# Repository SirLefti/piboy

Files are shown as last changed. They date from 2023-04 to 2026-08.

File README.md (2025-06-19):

PiBoy
=========================



<br>




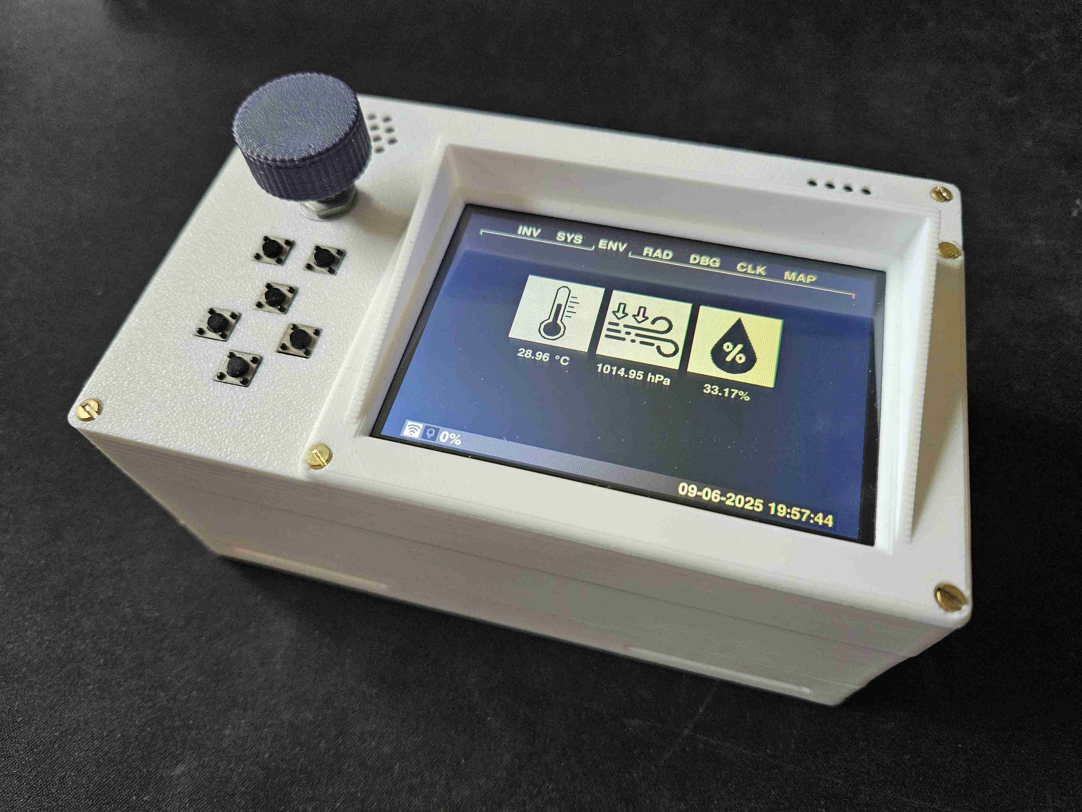
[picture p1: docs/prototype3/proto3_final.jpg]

Build your own Pip-Boy with some useful features for real-life using your Raspberry Pi.

## Features

#### File Manager App
Provides basic functions for moving, copying and deleting files and directories. Plug in a USB drive as a holo tape.

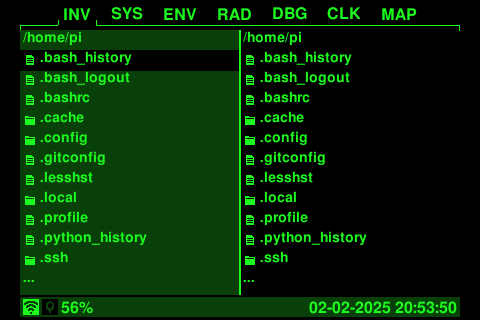
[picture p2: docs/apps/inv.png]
inv


#### System App
Can fetch and install updates from the git repository.

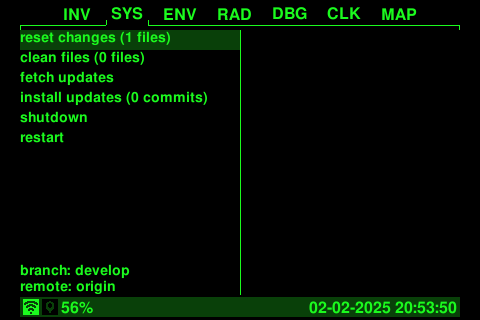
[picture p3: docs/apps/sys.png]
sys


#### Environment App
Provides useful information about your environment like temperature, atmospheric pressure and humidity.

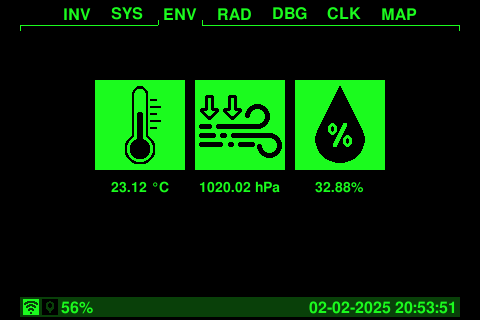
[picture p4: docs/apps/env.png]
env


#### Radio App
Actually more like a classic music player. Stay tuned!

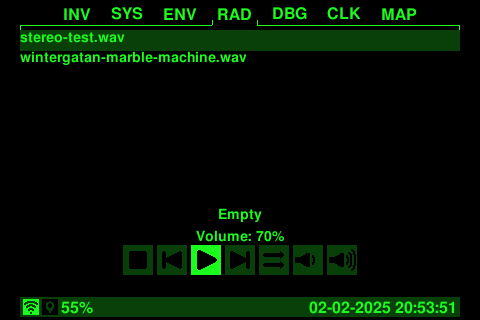
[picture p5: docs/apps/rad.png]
rad


#### Debug App
Shows the last pressed key to help you check the key wiring.

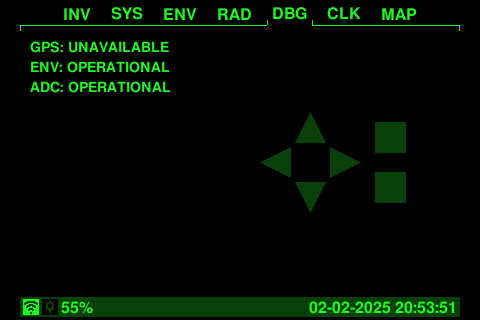
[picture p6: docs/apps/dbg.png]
dbg


#### Clock App
It just shows the time on a classic analog clock.

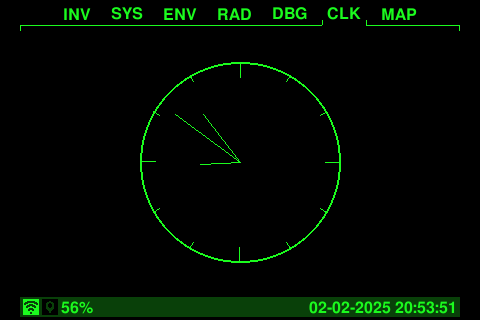
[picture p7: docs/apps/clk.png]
clk


#### Map App
Supports zooming and moving the map around. Don't get lost in the wasteland.

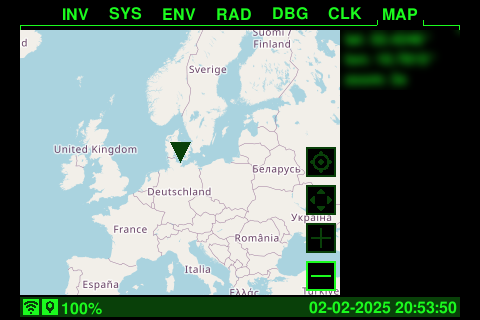
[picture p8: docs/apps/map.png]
map


## Hardware

Base:
- Raspberry Pi (full size board with all 40 pins recommended)
- Waveshare 3.5" SPI display (or [compatible](http://www.lcdwiki.com/3.5inch_RPi_Display))
- [GPIO edge extension](https://wiki.52pi.com/index.php?title=EP-0121)
- rotary encoder module (KY-040)
- 6x micro push buttons (6 mm x 6 mm)
- proto board (14x9 holes required)
- wires, general soldering stuff
- rotary encoder knob (optional, choose one you like)
- USB Wi-Fi adapter (optional, but recommended if your Pi does not have Wi-Fi onboard)

Modules:
- BME280 environment sensor
- NEO-6M GPS module
- DS3231 RTC clock (optional, but recommended, Raspberry Pi 5 features its own integrated RTC, that just requires to
connect a battery)
- ADS1115 analog-digital converter

Audio:
- PAM8403 amplifier with potentiometer
- 2x Mini Speakers (e.g. Loudity 16 mm or Adafruit Oval 20 mm x 30 mm)
- capacitor ~1000 µF, 10-25 V (optional, but recommended to stabilize power when turning on the PAM8403)
- potentiometer knob (optional, choose one you like)

Battery power:
- MT3608 power converter
- TP4056 battery charging controller
- 18650 battery cell (others can fit as well)
- toggle switch

Additional parts depending on case variant (see [Assembly](#assembly)). Check the following matrix to see which components and component groups are
supported by which case variant. Modules can be skipped entirely, but apps depending on them will not work properly.
Audio can be skipped as well if audio output is not needed. You can also use the audio jack of your Raspberry Pi if it
has one, but not all case provide an opening for it (but you can always make an opening for it). 

### Component Support Matrix

| Component | Prototype 1 | Prototype 2 | Prototype 3 |
|---|---|---|---|
| BME280 | &cross; | &check; | &check; |
| NEO-6M | &cross; | &check; | &check; |
| DS3231 | &cross; | &check; | &check; |
| ADS1115 | &cross; | *see note below* | &check; |
| Audio Components | &cross; | &cross; | &check; |
| Battery Components  | &cross; | &check; | &check; |
| GPIO Edge Extension | &cross; | *see note below* | &check; |

> **NOTE:**<br>
> ADS1115 can be squeezed into prototype 2 as well, but there is no dedicated place for it, and it is not documented.

> **NOTE:**<br>
> The GPIO edge extension can be used in one of the two variants of prototype 2.

### Raspberry Pi Model Support

PiBoy can work with models of the Raspberry Pi, that:

* have 40 GPIO pins (which excludes non-plus variants of the first generation)
* support the usual rectangular stand-off grid (which excludes again non-plus variants of the first generation)
* are ideally full width (which excludes all Zero models)
* are ideally full length (which excludes all A+ models and Zero models)

Zero models support only one half of the usual rectangular stand-off grid due to their size, which makes them less
stable in the case than full size models. Official support for Zero models is possible in future case variants. 

Short models like A+ and Zero models will also not reach the end of the case with their IO, Zero models do not even
provide IO on that end. This will prevent you from plugging in USB drives and it will look odd. Apart from that, they
can be used as well.

In short, all models with ethernet and 4x USB are ideal, *BUT* there is one exception: The model 4B swapped the 
positions of the ethernet and USB ports, which requires different structures in the case around the IO. The model 5 went
back to the old layout, and this will most likely be used in future models as well. Prototypes 1 and 2 are using the old
layout as well, making them incompatible with the 4B. Prototype 3 introduces replaceable IO plates to support both
layouts. You can also design your own IO plate to make it compatible with other single board computers, that have a
completely different IO layout.

## Installation

All guides are using Raspberry OS based on Debian Bookworm.

Install system dependencies:
````bash
sudo apt install git libopenjp2-7 libportaudio2 libopenblas0 python3-rpi-lgpio fonts-freefont-ttf
````

Call `sudo raspi-config`, select `Interface Options > SPI` and choose `Yes` to enable SPI.
Then select `Interface Options > I2C` and choose `Yes` to enable I2C.
Then also select `Interface Options > Serial Port` and choose `No` in the first pop-up and `Yes` in the second
pop-up. The last pop-up should then inform you, that the serial login shell is disabled and the serial interface is
enabled.

Clone repository and go into it:
````bash
git clone https://github.com/SirLefti/piboy
cd piboy
````

Create a virtual environment:
````bash
python -m venv .venv
````

Install python dependencies:
````bash
.venv/bin/pip install -r requirements-pi.txt
````

Now head over to the [module specific instructions](#module-specific-instructions) section and check the instructions of
each module you want to use. Some of them require additional steps to make them work. They all provide information to
validate that the module is configured and wired correctly.

Create a systemd service in ``/etc/systemd/system/piboy.service``:
````ini
[Unit]
Description=PiBoy Python Script
After=network.target

[Service]
Type=simple
WorkingDirectory=/home/pi/piboy
ExecStart=/home/pi/piboy/.venv/bin/python -u /home/pi/piboy/piboy.py
Restart=on-failure
User=pi
Group=pi

[Install]
WantedBy=multi-user.target
````

Reload to get the new configuration:
````bash
sudo systemctl daemon-reload
````

Activate the new service:
````bash
sudo systemctl enable piboy.service
````

Either restart the Pi or start the service manually:
````bash
sudo systemctl start piboy.service
````

## Configuration

On first run, the PiBoy script will create a ``config.yaml`` if not found. In that config file, you can configure
everything that relates to appearance and wiring. When running on a Raspberry Pi, ``dev_move`` must be set to ``false``
if not set by default. For development, it must be set to ``true`` instead, obviously. This setting automatically loads
the right input and display modules. On a Raspberry Pi, ``ILI9486Display`` and ``GPIOInput`` are being used. For
development, ``TkInteraction`` or ``SelfManagedTkInteraction`` can be used, both implement full input and display
functionality.

You can define additional color groups under ``app_config/modes`` for your own theme and set the index at
``app_config/color_mode``. The first default color group is the traditional classic green theme, the second is a yellow
power armor theme.

This project uses FreeSansBold as default font. If the font cannot be found despite being installed, or you do not want
to install it, place the ``FreeSansBold.ttf`` in the root directory as a workaround.

## Assembly

See [instructions for prototype 1](docs/prototype1/ASSEMBLY.md).

See [instructions for prototype 2](docs/prototype2/ASSEMBLY.md).

See [instructions for prototype 3](docs/prototype3/ASSEMBLY.md).

### Module specific instructions

* [BME280 environmental sensor](docs/BME280.md)
* [DS3231 RTC clock](docs/DS3231.md)
* [NEO-6M GPS module](docs/NEO-6M.md)
* [ADS1115 analog-digital converter](docs/ADS1115.md)
* [KY-040 rotary encoder](docs/rotary-encoder.md)
* [Keypad](docs/keypad.md)
* [Power circuit](docs/power-circuit.md)

## Post-Install

### Wi-Fi connection

You might want to add another Wi-Fi connection, e.g. to your phone, when you are out of your homes Wi-Fi range. Get in
the range of the Wi-Fi you want to add and check, if your device can see it:
````bash
nmcli dev wifi
````
If your Wi-Fi is not found immediately, wait a bit and run the command again.

If it was found, you can configure the connection (replace `<wifi-ssid>` and `<wifi-password>`):
````bash
sudo nmcli dev wifi connect <wifi-ssid> password <wifi-password>
````
When you were connected via `ssh`, the connection might reset due to the network change.

Network configurations are saved at `/etc/NetworkManager/system-connections`. Refer to the documentation of `nmcli` for
further details.

## Roadmap

We are feature complete. But there is still room for software and case improvements.

* [x] display driver
* [x] project base
* [x] build documentation / guide
* [x] case
* [x] file manager app
* [x] map app
* [x] radio app
* [x] environment sensors (temperature, humidity, ...)
* [x] GPS module
* [x] battery power
* [x] speaker for radio app
* [x] battery status
* [x] auto-mount usb drives
* [x] improved case

## Issues

### PyAudio

`pyaudio` might require system dependencies to be installed. On macOS, install the `portaudio` dependency with MacPorts:
```bash
sudo port install portaudio
```
Then install the package with pip and pass the directories where to find the dependencies:
```bash
CFLAGS="-I/opt/local/include -L/opt/local/lib" .venv/bin/pip install pyaudio
```

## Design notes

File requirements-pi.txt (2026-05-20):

-r requirements.txt
# The following requirements are only used by the hardware modules for Raspberry Pi.
spidev >= 3.5
rpi-lgpio >= 0.6.0
RPi.bme280 >= 0.2.4
evdev >= 1.7.1

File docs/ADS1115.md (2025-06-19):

ADS1115 analog-to-digital converter
===================================

The ADS1115 is a four-channel ADC with 16-bit resolution communicating via I2C. It can be used to bring analog input to
platforms, that do not provide analog input themselves.

## Wiring

The analog input voltage cannot be higher than the supply voltage. Because the use case is to measure the battery
voltage, the supply voltage for the module must be 5 V. To measure the battery cell voltage, an analog input must be
connected to it.

| ADS1115 Pin | Raspberry Pi/Power Converter Pin |
|---|---|
| GND | Pi GND |
| VDD | Pi VCC (5 V) |
| SDA | Pi SDA (GPIO 2) |
| SCL | Pi SCL (GPIO 3) |
| A0 | MT3608 VIn+ |

I2C is a bus system. Other devices can be connected to the same pins, but still work at the same time if they have
different addresses. ADS1115 are usually using address 0x48. Most boards also have an ADDR pin that allows to select
from different addresses by connecting that pin to GND, VDD, SDA or SCL.

## Configuration

Install ``i2c-tools`` if not already done:
```bash
sudo apt install i2c-tools
```

Check if the module is recognized correctly:
```bash
sudo i2cdetect -y 1
```
This command should return an entry in the matrix for 0x48 (or a different address if the module has a different one,
example):
```
     0  1  2  3  4  5  6  7  8  9  a  b  c  d  e  f
00:                         -- -- -- -- -- -- -- --
10: -- -- -- -- -- -- -- -- -- -- -- -- -- -- -- --
20: -- -- -- -- -- -- -- -- -- -- -- -- -- -- -- --
30: -- -- -- -- -- -- -- -- -- -- -- -- -- -- -- --
40: -- -- -- -- -- -- -- -- 48 -- -- -- -- -- -- --
50: -- -- -- -- -- -- -- -- -- -- -- -- -- -- -- --
60: -- -- -- -- -- -- -- -- -- -- -- -- -- -- -- --
70: -- -- -- -- -- -- -- --
```

Open a python console and test it out:
```pycon
>>> import smbus2
>>> bus = smbus2.SMBus(1)
>>> address = 0x48  # address of your sensor board, as shown in i2cdetect
>>> channel = 0  # channel number that is connected to a voltage source
>>> config = [0b11000001 | (channel << 4), 0b10000011]
>>> bus.write_i2c_block_data(address, 0x01, config)
>>> word_data = bus.read_word_data(address, 0x00)
>>> raw_data = ((word_data & 0xFF) << 8) | (word_data >> 8)  # byte swap
>>> (raw_data if raw_data < 0x8000 else raw_data - 0x10000) * 6.144 / 0x8000
3.8289375  # example output
```

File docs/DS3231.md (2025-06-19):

DS3231 hardware RTC module
==========================

The DS3231 is a hardware RTC module communicating via I2C. This module can be used to keep the current time when the Pi
is powered off. When booting, the Pi has to resync the system time by either the network or a hardware clock. If no 
network is available, the hardware clock acts as a fallback.

## Wiring

DS3231 modules have typically six pins in total. We need just four of them.

| DS3231 Pin | Raspberry Pi Pin |
|---|---|
| GND | GND |
| VCC | VCC (3.3 V) |
| SDA | SDA (GPIO 2) |
| SCL | SCL (GPIO 3) |
| SQW | not connected |
| 32K | not connected |

I2C is a bus system. Other devices can be connected to the same pins, but still work at the same time if they have
different addresses. DS3231 are usually using address 0x68.

## Configuration

Install ``i2c-tools`` if not already done:
```bash
sudo apt install i2c-tools
```

Check if the module is recognized correctly:
```bash
sudo i2cdetect -y 1
```
This command should return an entry in the matrix for 0x68 (or a different address if the module has a different one,
example):
```
     0  1  2  3  4  5  6  7  8  9  a  b  c  d  e  f
00:                         -- -- -- -- -- -- -- --
10: -- -- -- -- -- -- -- -- -- -- -- -- -- -- -- --
20: -- -- -- -- -- -- -- -- -- -- -- -- -- -- -- --
30: -- -- -- -- -- -- -- -- -- -- -- -- -- -- -- --
40: -- -- -- -- -- -- -- -- -- -- -- -- -- -- -- --
50: -- -- -- -- -- -- -- 57 -- -- -- -- -- -- -- --
60: -- -- -- -- -- -- -- -- 68 -- -- -- -- -- -- --
70: -- -- -- -- -- -- -- --
```
The entry on 0x57 is apparently the EEPROM found on the module.

Add the following entry to `/boot/firmware/config.txt`:
```
dtoverlay=i2c-rtc,ds3231
```

Reboot the pi and run the command again:
```bash
sudo i2cdetect -y 1
```

The address should now be marked as `UU`, which indicates that the devices is being used by a system driver (example):
```
     0  1  2  3  4  5  6  7  8  9  a  b  c  d  e  f
00:                         -- -- -- -- -- -- -- --
10: -- -- -- -- -- -- -- -- -- -- -- -- -- -- -- --
20: -- -- -- -- -- -- -- -- -- -- -- -- -- -- -- --
30: -- -- -- -- -- -- -- -- -- -- -- -- -- -- -- --
40: -- -- -- -- -- -- -- -- -- -- -- -- -- -- -- --
50: -- -- -- -- -- -- -- 57 -- -- -- -- -- -- -- --
60: -- -- -- -- -- -- -- -- UU -- -- -- -- -- -- --
70: -- -- -- -- -- -- -- --
```

Checking if it really works can be a bit tricky. The simplest way is having the display attached and the script
automatically running, because it shows date and time on the display. Make sure it is not connected to the network or
internet by removing the Wi-Fi adapter or ethernet cable if you are using one of those, or just by leaving your Wi-Fi
range when you are using onboard Wi-Fi.

Shut down the Pi and wait some time before booting it up again. If the time shown is relatively close to a reference
clock, the module was wired and configured correctly.

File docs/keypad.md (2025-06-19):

Keypad
======

The keypad uses six micro push buttons for a simple d-pad and two additional buttons.

## Parts
* 6x micro push buttons
* perf board/proto board (14x9 holes required)
* wires, general soldering stuff

## Assembly

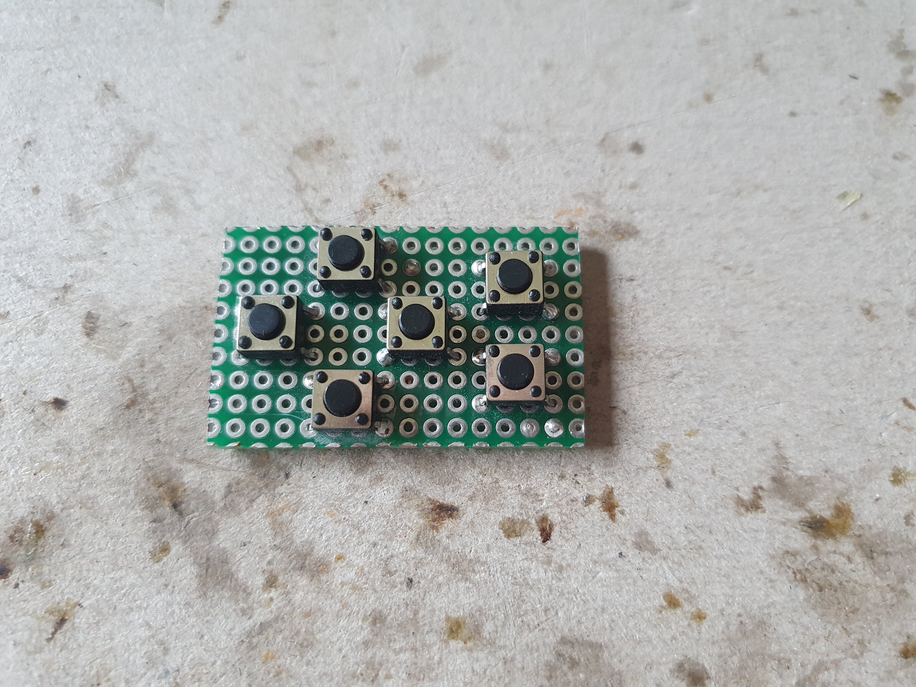
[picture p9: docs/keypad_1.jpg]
keypad_1

Mount and solder the micro push buttons as shown.

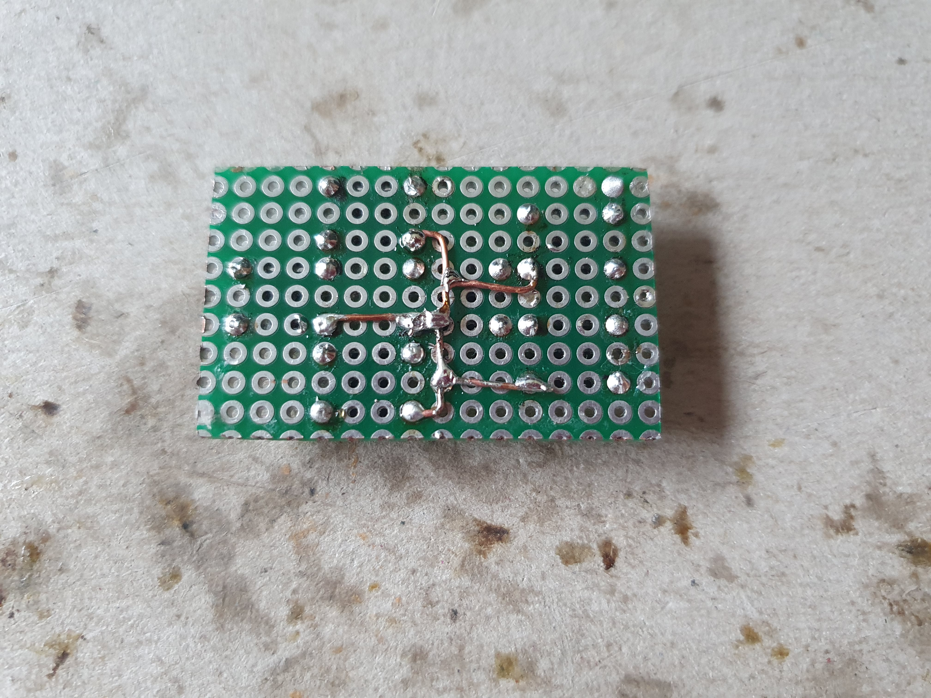
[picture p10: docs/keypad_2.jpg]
keypad_2

Solder a common ground wire.

Cut the edges of the board if it is too big to fit.

**NOTE:** As you can see, a single button needs 3x4 holes and has four legs, with two legs being connected to each other
internally. To connect each button to the Pi, use the leg of the button, that is just **one** hole apart from that one,
that is connected to the common ground wire. It might feel more intuitive to you to use the one, that is **two** holes
apart from the common ground wire, and I did this mistake several times as well. It is the other one. It does not damage
the Pi when it is soldered the wrong way, it is just not working.

## Wiring

| Keypad Pin | Raspberry Pi Pin |
|---|---|
| GND | GND |
| button UP | GPIO 5 |
| button DOWN  | GPIO 6 |
| button LEFT  | GPIO 12 |
| button RIGHT | GPIO 13 |
| button A | GPIO 16 |
| button B | GPIO 26 |

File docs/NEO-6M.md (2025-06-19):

NEO-6M GPS module
================

The NEO-6M is a GPS module communicating via UART. It provides the current position of the device.

## Wiring

The NEO-6M module has four pins in total.

| NEO-6M Pin | Raspberry Pi Pin |
|---|---|
| GND | GND |
| VCC | VCC (5 V) |
| RX | TX (GPIO 14) |
| TX | RX (GPIO 15) |

The RX pin on the module can be skipped and is not needed for now.

## Configuration

Check if the module is wired correctly and sends some data:
```bash
cat /dev/serial0
```
It might return lines like this:
```
$GPTXT,01,01,01,NMEA unknown msg*58
```

If not, try this instead:
```bash
tail -f /dev/serial0
```

If `/dev/serial0` does not exist, try it again with `/dev/ttyAMA0` instead. In that case, you have to change this value
in the `config.yaml` as well.

If the blue LED on the module is blinking, it has already found its position and sends messages with the position. Go
outside or close to a window and wait a few minutes if it does not blink.

Open a python console and test it out:
```pycon
>>> import serial
>>> import io
>>> import pynmea2
>>> device = serial.Serial('/dev/serial0', baudrate=9600, timeout=0.5)
>>> io_wrapper = io.TextIOWrapper(io.BufferedReader(device))
>>> while True:
...     data = io_wrapper.readline()
...     if data[0:6] == '$GPGLL':
...         message = pynmea2.parse(data)
...         print('lat:', message.latitude, 'lon:', message.longitude)
```

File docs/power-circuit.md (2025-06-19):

Power Circuit
=============

The power circuit provides battery power to this project, to use it without external power supply. It supports a 
standard 18650 battery cell, but can fit any other smaller sizes as well. 

## Parts
* 1x MT3608 power converter
* 1x TP4056 battery charging controller
* 1x 18650 Li-ion battery cell (others can fit as well)
* 1x toggle switch
* 1x capacitor ~1000 µF, 10-25 V (optional, but recommended, especially when using the PAM8403)
* wires and soldering stuff

## Assembly

Solder the parts together as shown in the table and image below.

**IMPORTANT:** Set up the power converter to output 5.0 V before soldering the Pi to it. The Pi has no fuses to protect
itself from over-voltage via the pins. Charge the battery before configuring it.

**NOTE**: The switch is placed between the battery/charging controller and the power converter, because the power
converter would drain the battery over time if it was permanently connected to it.

| from | to |
|---|---|
| battery+ | TP4056 B+ |
| battery- | TP4056 B- |
| TP4056 Out+ | Switch Center 1 |
| TP4056 Out- | Switch Center 2 |
| Switch Left 1 | MT3608 VIn+ |
| Switch Left 2 | MT3608 VIn- |
| MT3608 VOut+ | Pi Pin 2 (5V) |
| MT3608 VOut- | Pi Pin 6 (GND)  |
| Capacitor + (long leg)  | MT3608 VOut+ |
| Capacitor - (short leg) | MT3608 VOut- |

The complete circuit should look like this. Try to power it on like that to see if everything works. Also attach the
display module, because it has a relatively high power draw compared to the other components.
power-circuit
*Note: This example uses two separate cells instead of the single 18650 one. If using two separate cells, make sure they
are of the same type and have the same rated capacity. These are harvested from disposable e-vapes.*

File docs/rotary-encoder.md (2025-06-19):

Rotary Encoder
==============

A rotary encoder can be used in two different ways: By polling and by device overlay. Polling means checking the pins
over and over again in a short period of time, the device overlay on the other hand is an event based system. The device
overlay way is used here, because it is much more reliable.

## Wiring

A rotary encoder has two channels, channels A and B. On the KY-040 they are named CLK and DT for some reason, indicating
some clock and data pins, which is not really the case.

Connecting the rotary switch is optional. It can be used to call any function for debugging, like resetting the display.

| Rotary Encoder Pin | Raspberry Pi Pin |
|---|---|
| GND | GND |
| + | VCC (3.3 V) |
| CLK | GPIO 23 |
| DT | GPIO 22 |
| SW | GPIO 27 / NC |

## Configuration

To register the rotary encoder as a device, add this to `/boot/firmware/config.txt`:

```
dtoverlay=rotary-encoder,pin_a=22,pin_b=23,relative_axis=1,steps-per-period=1
```

Reboot the Pi.

Install ``evtest`` if not already done:
```bash
sudo apt install evtest
```

Calling ``evtest`` should return a list of input devices:
```
No device specified, trying to scan all of /dev/input/event*
Not running as root, no devices may be available.
Available devices:
/dev/input/event0:      rotary@16
/dev/input/event1:      vc4-hdmi
/dev/input/event2:      vc4-hdmi HDMI Jack
```

The rotary shows up as ``/dev/input/event0``. Quit the command with ``Ctrl+C``.

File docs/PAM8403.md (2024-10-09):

PAM8403 amplifier module
========================

The PAM8403 is a compact amplifier module to drive small speakers.

It comes in various variants, some include a potentiometer to control the volume. This is the recommended variant for
this project.

## Wiring and Configuration

The module usually uses 5 V. Two speakers can be connected.

| PAM8403 Pin | Raspberry Pi/Speaker Pin |
|---|---|
| Power - | Pi GND |
| Power + | Pi VCC (5 V) |
| Lout - | Left Speaker GND |
| Lout + | Left Speaker Signal |
| Rout - | Right Speaker GND |
| Rout + | Right Speaker Signal |
| L | *see below* |
| G | *see below* |
| R | *see below* |

The input can be connected in two ways:

---

### A: via 3.5 mm audio jack

Most boards (first to fourth generation inclusively) provide an audio jack for headphones. We can use this to connect
the signal to the amplifier. You can check out the
[Raspberry Pi Documentation](https://github.com/raspberrypi/documentation/blob/develop/documentation/asciidoc/computers/raspberry-pi/raspberry-pi-schematics.adoc)
for schematics. Most boards provide names checkpoints for audio that can be used to solder a connection to.

For Raspberry Pi 2 and 3 boards (probably also Pi 1, but it is not referenced in the schematics):

| PAM8403 Pin | Raspberry Pi Checkpoint |
|---|---|
| L | PP25 |
| G | PP6 |
| R | PP26 |

For Raspberry Pi 4 boards:

| PAM8403 Pin | Raspberry Pi Checkpoint |
|---|---|
| L | TP22 |
| G | TP7/TP8/TP9/TP12 |
| R | TP23 |

Raspberry Pi 5 (and probably onwards) and Zero Boards do not provide an audio jack. They can use the next variant.

---

### B: via GPIO pins

GPIO pins can be configured to output audio signals. To enable this, add this to `/boot/firmware/config.txt`:

```
dtoverlay=pwm-2chan,pin=18,func=2,pin2=19,func2=2
```

The input can then be wired as follows:

| PAM8403 Pin | Raspberry Pi Pin |
|---|---|
| L | GPIO 18 |
| G | GND |
| R | GPIO 19 |

---

To test it out, get some audio files and try to play them from the command line. You can use `aplay`, which is
preinstalled, to play `.wav` files. For `.mp3` files, you can use `mpg123`, which has to be installed separately.

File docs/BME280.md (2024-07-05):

BME280 environmental sensor
===========================

The BME280 is an environmental sensor communicating via I2C. The sensor can read the current temperature, humidity and
atmospheric pressure.

## Wiring

The BME280 has usually four pins and a single mounting hole. There might be other variants out there, but be careful:
Some shop might try fool you and sell you the cheaper BMP280 instead, which lacks the humidity feature and has usually
a different board with six pins and two mounting holes. The case parts are not prepared to mount this variant.

Also, following the datasheets, some variants needs to be supplied with 3.3 V, while others expect 5 V instead. Read
carefully.

In my case, it was documented with 3.3 V.

| BME280 Pin | Raspberry Pi Pin |
|---|---|
| GND | GND |
| VIn | VCC (3.3 V) |
| SDA | SDA (GPIO 2) |
| SCL | SCL (GPIO 3) |

I2C is a bus system. Other devices can be connected to the same pins, but still work at the same time if they have
different addresses. BME280 are usually using address 0x76.

## Configuration

Install ``i2c-tools`` if not already done:
```bash
sudo apt install i2c-tools
```

Check if the module is recognized correctly:
```bash
sudo i2cdetect -y 1
```
This command should return an entry in the matrix for 0x76 (or a different address if the module has a different one,
example):
```
     0  1  2  3  4  5  6  7  8  9  a  b  c  d  e  f
00:                         -- -- -- -- -- -- -- --
10: -- -- -- -- -- -- -- -- -- -- -- -- -- -- -- --
20: -- -- -- -- -- -- -- -- -- -- -- -- -- -- -- --
30: -- -- -- -- -- -- -- -- -- -- -- -- -- -- -- --
40: -- -- -- -- -- -- -- -- -- -- -- -- -- -- -- --
50: -- -- -- -- -- -- -- -- -- -- -- -- -- -- -- --
60: -- -- -- -- -- -- -- -- -- -- -- -- -- -- -- --
70: -- -- -- -- -- -- 76 --
```

Open a python console and test it out:
```pycon
>>> import smbus2
>>> import bme280
>>> bus = smbus2.SMBus(1)
>>> address = 0x76  # address of your sensor board, as shown in i2cdetect
>>> bme280.sample(bus, address)
compensated_reading(id=... timestamp=..., temp=23.020 °C, pressure=1002.68 hPa, humidity=38.15 % rH)
```
If the reading returns just zeroes for `temp`, `pressure` and `humidity`, check your wiring. The reading was not
successful, unless you are living in an extremely dry, but cool place in outer space, and the values are actually
correct.

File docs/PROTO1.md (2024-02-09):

Case Prototype 1
================

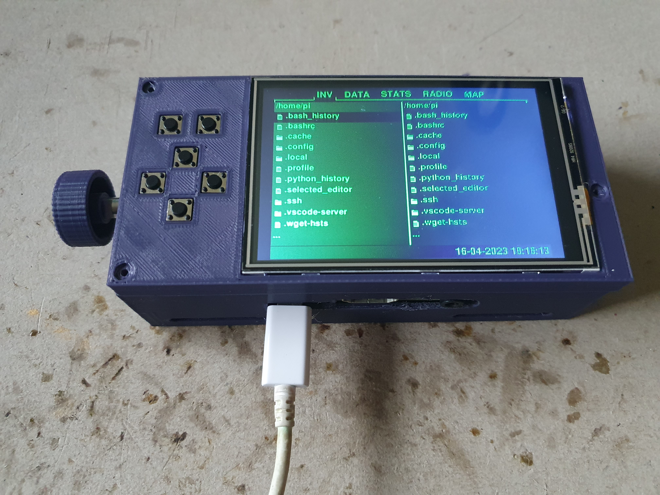
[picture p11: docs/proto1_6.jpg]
proto1_final


## Parts
* [base part](parts/proto1/Proto1.1-base.stl)
* [top part](parts/proto1/Proto1.1-top.stl)
* 3x M2x25
* 6x micro push buttons (6mm x 6mm)
* rotary encoder (KY-040 module)
* perf board/proto board (14x9 holes required)
* wires, general soldering stuff
* rotary encoder knob (optional)

**Made for Raspberry Pi 2 Model B**

## Goal

* minimalistic case as a proof of concept
* test button position and alignment
* test bulge for forearm
* test space for a potential strap
* test printing and removing support structures
* no extra space for extra hardware modules or battery

## Evaluation

* forearm bulging requires huge support structure, maybe just make it flat or introduce a separate part and print it
upside down
* support posts for the pi board also require support structures beneath, because a strap should go underneath
* screw holes are pretty tight, but might allow to omit nuts
* hole for rotary encoder is a bit tight
* might need a custom knob which is flush with the case
* knob might be too close to your forearm, depending on its size
* misplaced support posts for Pi board
* missing cutout for audio jack
* SMDs under the display module might interfere
* right screw post blocks USB ports

### Fixes in Prototype 1.1

* added cutout for audio jack
* fixed misplaced support posts
* less tight screw holes in top part
* removed/shortened screw post on the right side

## Building

### 1. Prepare parts

proto1_parts
The first version of the 3d-printed parts have some issues. There is no cutout for the audio jack and the support posts
for the Pi board are misplaced. 

### 2. Solder daughter board

proto1_1
Mount and solder the micro push buttons as shown.

proto1_2
Solder a common ground wire.

Cut the edges of the board if it is too big to fit.

### 3. Solder to Pi board

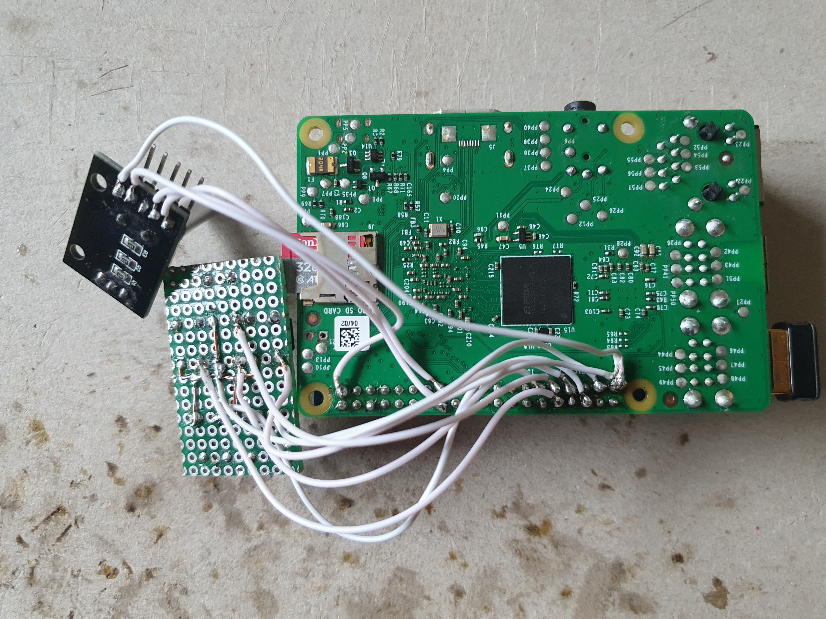
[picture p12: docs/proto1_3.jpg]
proto1_3

Solder wires to the bottom of the Pi board to connect the daughter board and rotary encoder. 

| #pin | pin name  | connects |
|---|---|---|
| 1 | 3v3 power | rotary encoder + |
| 15 | GPIO 22 | rotary encoder CLK |
| 16 | GPIO 23 | rotary encoder DT |
| 29 | GPIO 5 | button UP |
| 31 | GPIO 6 | button DOWN |
| 32 | GPIO 12 | button LEFT |
| 33 | GPIO 13 | button RIGHT |
| 36 | GPIO 16 | button A |
| 37 | GPIO 26 | button B |
| 39 | GND | rotary encoder GND, button GND |

Keep in mind, that wiring diagrams and pin-outs for the Pi are usually from a top view, which means you have mirror the
pinout, as seen in the image.

### 4. Assembly

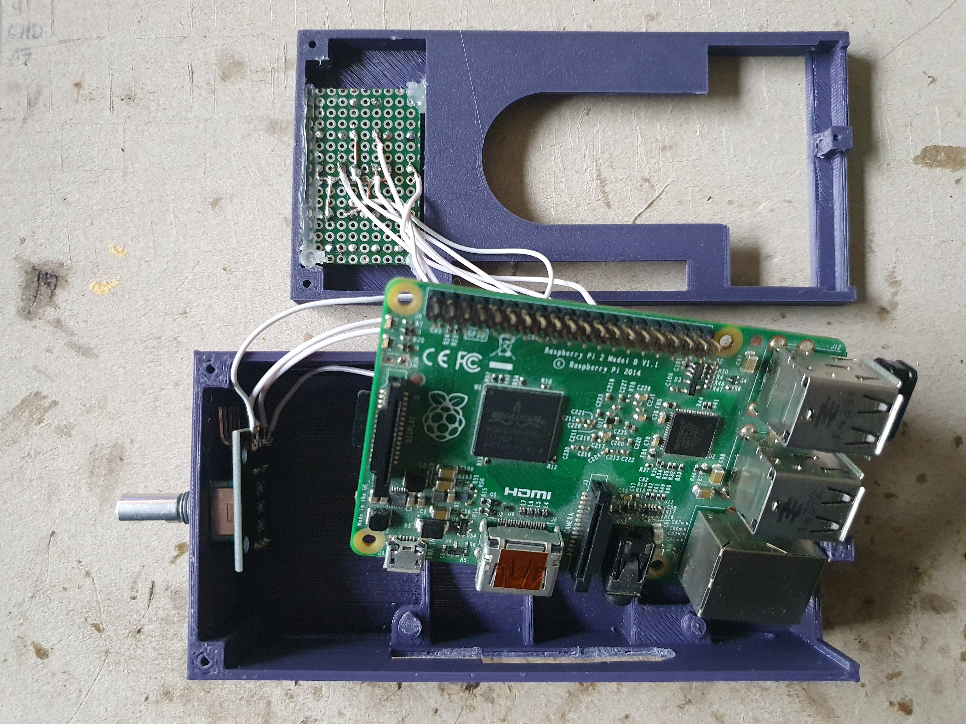
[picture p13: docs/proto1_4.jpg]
proto1_4

Mount the rotary encoder and glue in the daughter board (I used hot glue due to the gaps).

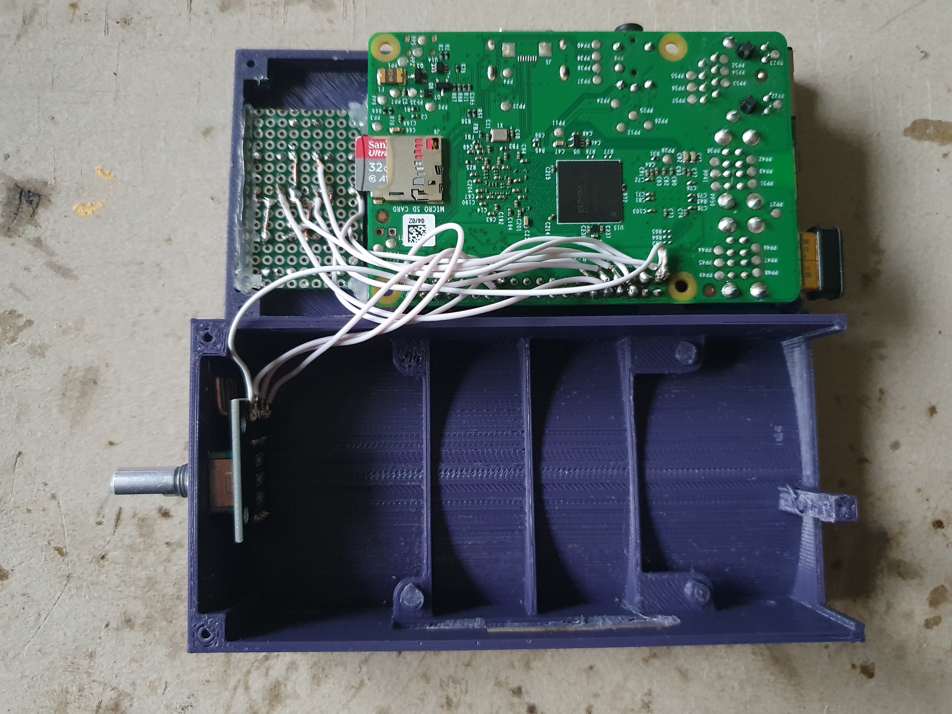
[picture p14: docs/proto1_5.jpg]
proto1_5

Flip the Pi board and attach the display module.

proto1_6
Put both parts together. Add a knob if you have and use screws to hold the parts in place.

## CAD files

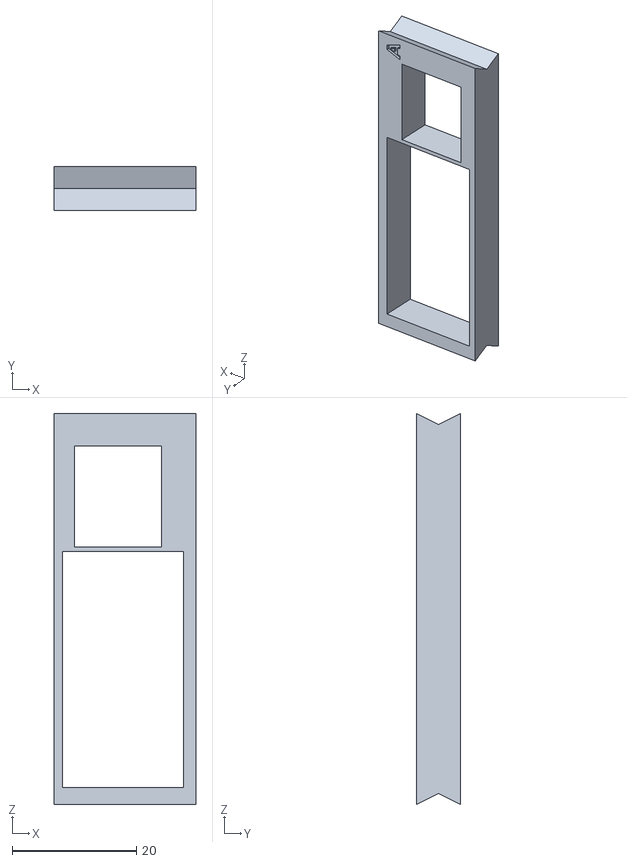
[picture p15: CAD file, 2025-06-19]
docs/prototype3/parts/Proto3-pi-2-3-5-plate.stl
22.8 x 7.00 x 62.9

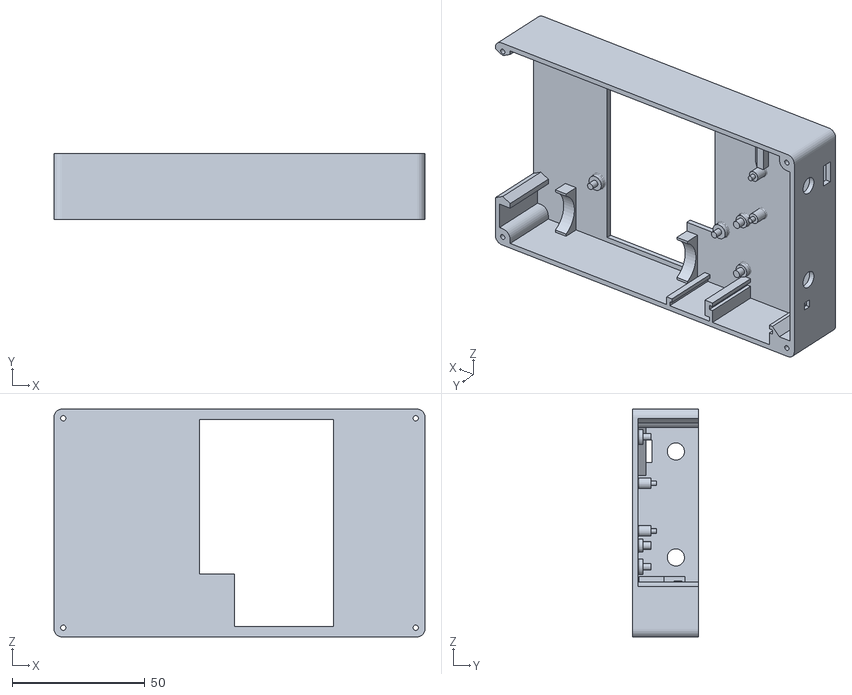
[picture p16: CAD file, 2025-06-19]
docs/prototype3/parts/Proto3-part-carrier.stl
140.0 x 24.8 x 86.0

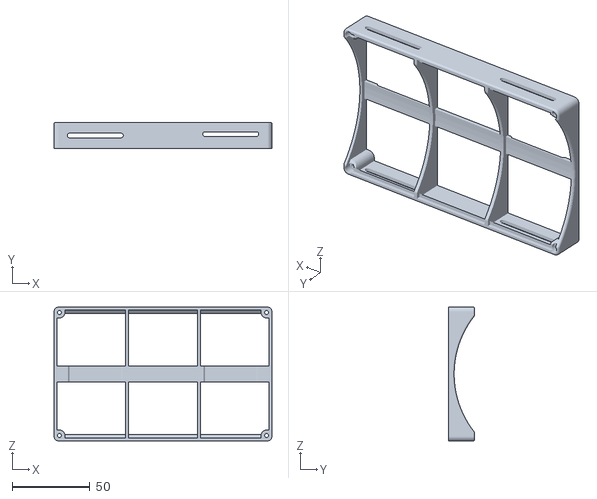
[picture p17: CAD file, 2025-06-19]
docs/prototype3/parts/Proto3-part-base-frame.stl
140.0 x 17.0 x 86.0

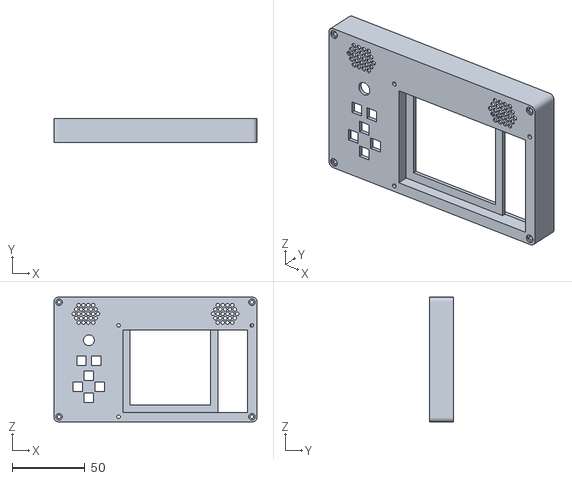
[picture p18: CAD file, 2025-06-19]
docs/prototype3/parts/Proto3-part-top.stl
140.0 x 16.8 x 86.0

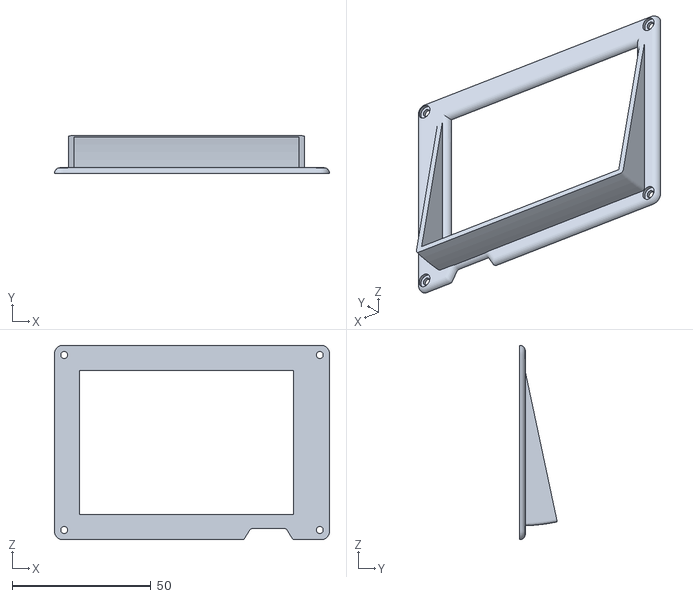
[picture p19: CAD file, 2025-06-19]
docs/prototype3/parts/Proto3-part-glare-shield.stl
99.0 x 13.5 x 70.0

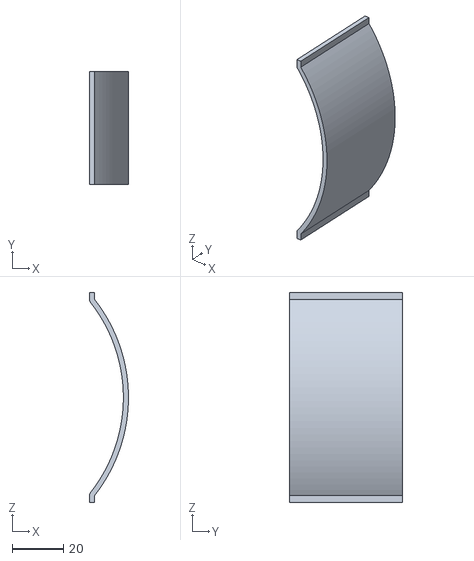
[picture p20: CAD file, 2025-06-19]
docs/prototype3/parts/Proto3-part-base-arch-3x.stl
15.2 x 44.0 x 82.0

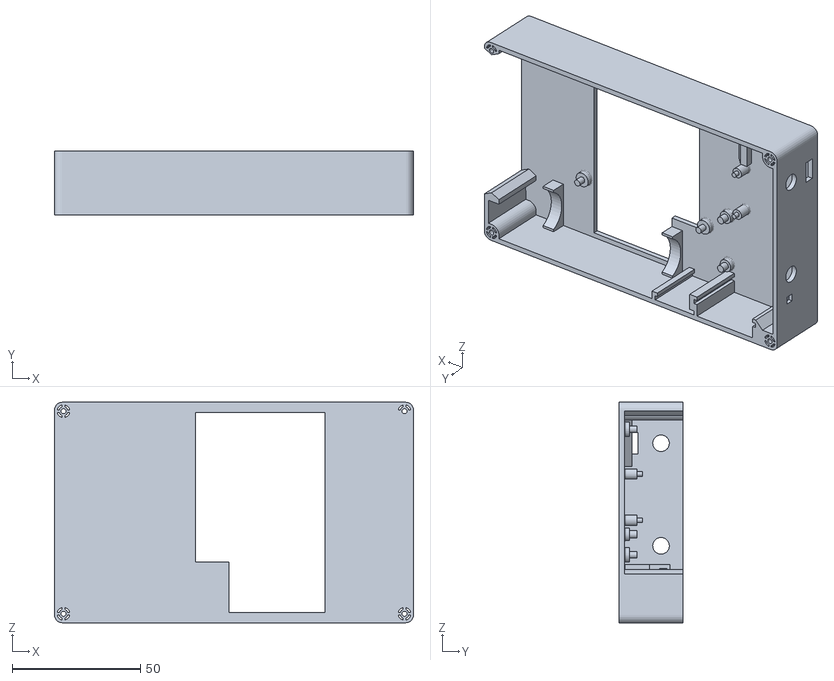
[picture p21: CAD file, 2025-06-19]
docs/prototype3/parts/Proto3-part-carrier-optimized.stl
140.0 x 24.8 x 86.0

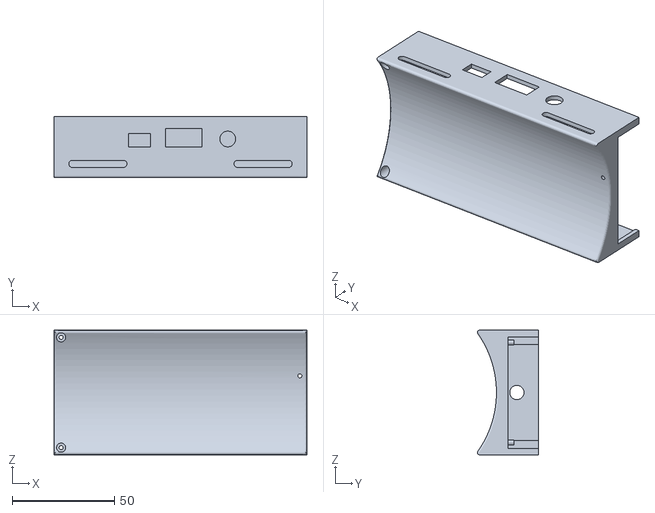
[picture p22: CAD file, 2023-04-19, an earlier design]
docs/prototype1/parts/Proto1.1-base.stl
123.9 x 30.1 x 61.0

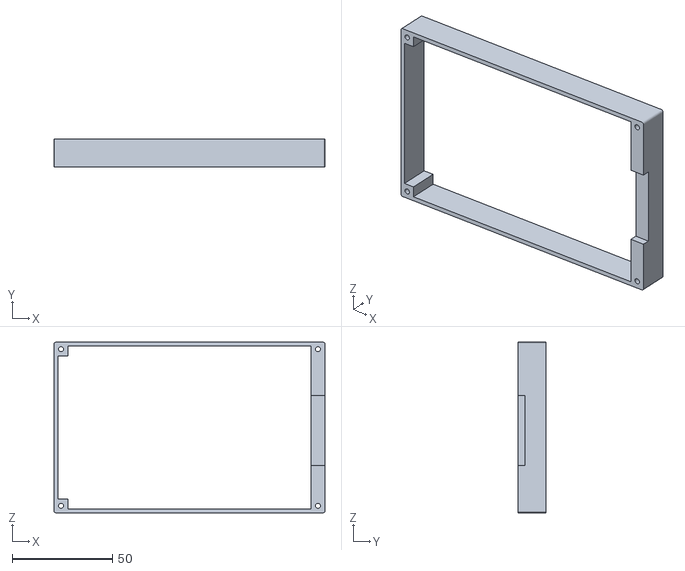
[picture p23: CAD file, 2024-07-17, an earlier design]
docs/prototype2/parts/Proto2.1-spacer.stl
135.0 x 14.0 x 85.0

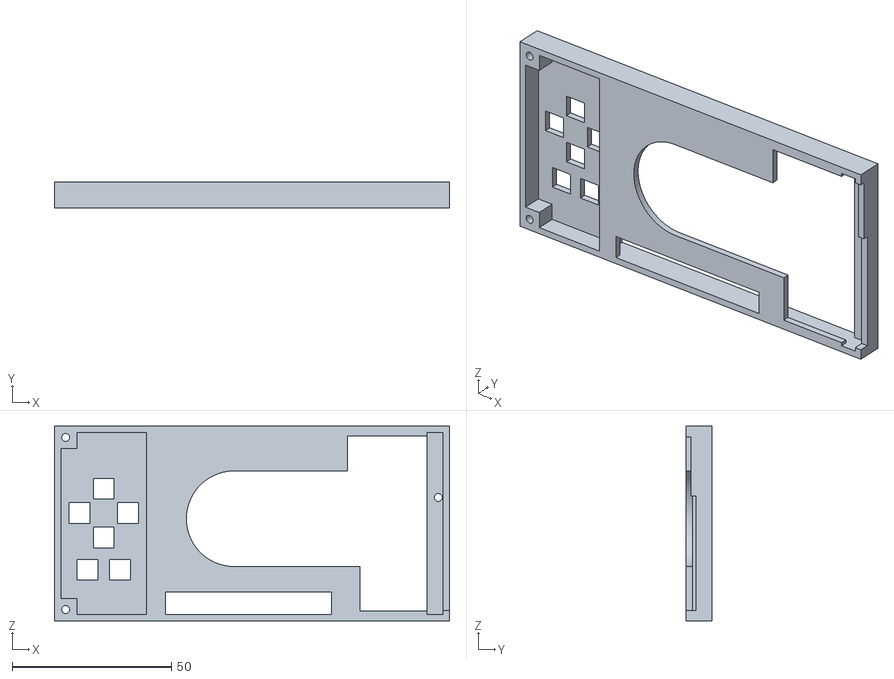
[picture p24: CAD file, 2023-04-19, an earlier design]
docs/prototype1/parts/Proto1.1-top.stl
123.9 x 8.00 x 61.0

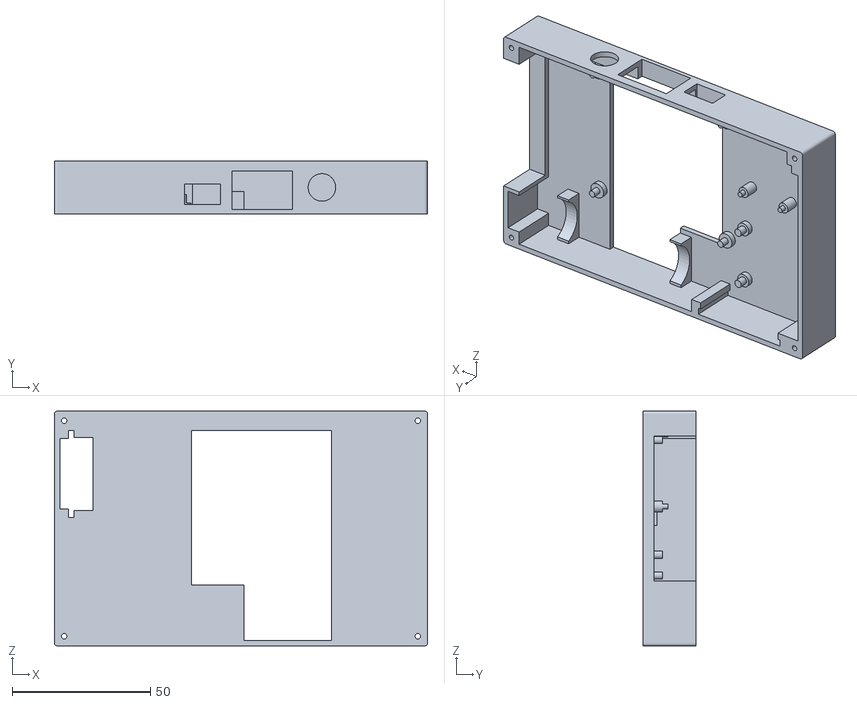
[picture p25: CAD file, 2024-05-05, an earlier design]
docs/prototype2/parts/Proto2.1-carrier.stl
135.0 x 19.1 x 85.0

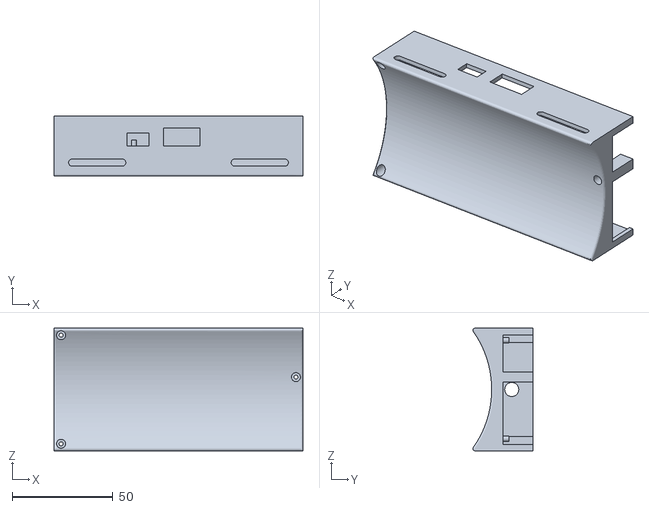
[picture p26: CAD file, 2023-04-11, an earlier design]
docs/prototype1/parts/Proto1-base.stl
123.9 x 30.1 x 61.0

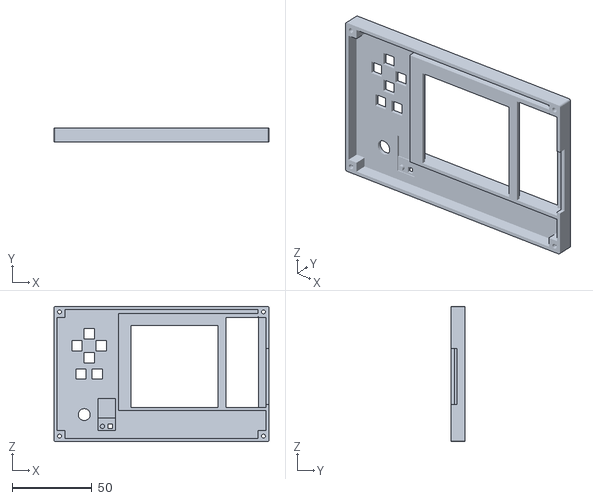
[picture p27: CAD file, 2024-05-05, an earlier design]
docs/prototype2/parts/Proto2.1-top-no-spacer.stl
135.0 x 8.50 x 85.0

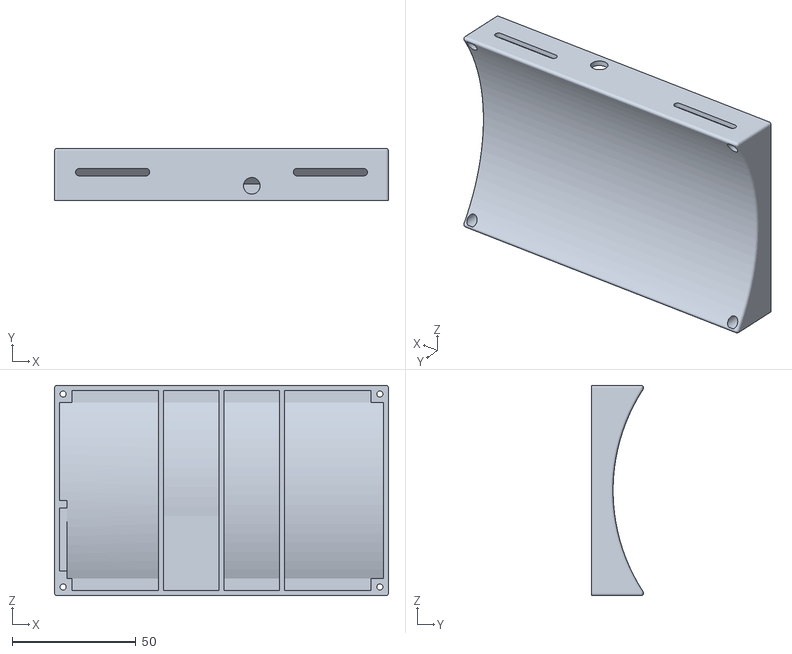
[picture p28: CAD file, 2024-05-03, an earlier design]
docs/prototype2/parts/Proto2.1-base.stl
135.0 x 21.1 x 85.0

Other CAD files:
docs/prototype3/parts/Proto3-pi-4-plate.stl
docs/prototype1/parts/Proto1-top.stl
docs/prototype2/parts/Proto2.1-top.stl
docs/prototype2/parts/Proto2-top.stl
docs/prototype2/parts/Proto2-base.stl
docs/prototype2/parts/Proto2-carrier.stl
docs/prototype2/parts/Proto2-spacer.stl
docs/prototype2/parts/Proto2-top-no-spacer.stl

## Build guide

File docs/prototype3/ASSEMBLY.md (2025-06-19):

Case Prototype 3
================

## Parts
* 1x [base frame part](parts/Proto3-part-base-frame.stl)
* 3x [base arch part](parts/Proto3-part-base-arch-3x.stl)
* 1x [carrier part](parts/Proto3-part-carrier.stl)
* 1x [top part](parts/Proto3-part-top.stl)
* 1x [glare shield](parts/Proto3-part-glare-shield.stl)
* 8x M2x25 screws
* 3x M2x10 screws + nuts

either for Raspberry Pi 2B, 3B or 5:
* 1x [IO plate for RPi 2B, 3B and 5](parts/Proto3-pi-2-3-5-plate.stl)

or for Raspberry Pi 4B:
* 1x [IO plate for RPi 4B](parts/Proto3-pi-4-plate.stl)

or your own designed one if you use a different single board computer.

There is also an alternative [optimized carrier part](parts/Proto3-part-carrier-optimized.stl), that has some print
optimizations around the screw holes to ensure enough structural strength while avoiding too much slicer optimization.
Use it only if your 3D printer is capable of such fine structures or use the normal part from the list above instead.

## Instructions

### 1. Prepare parts

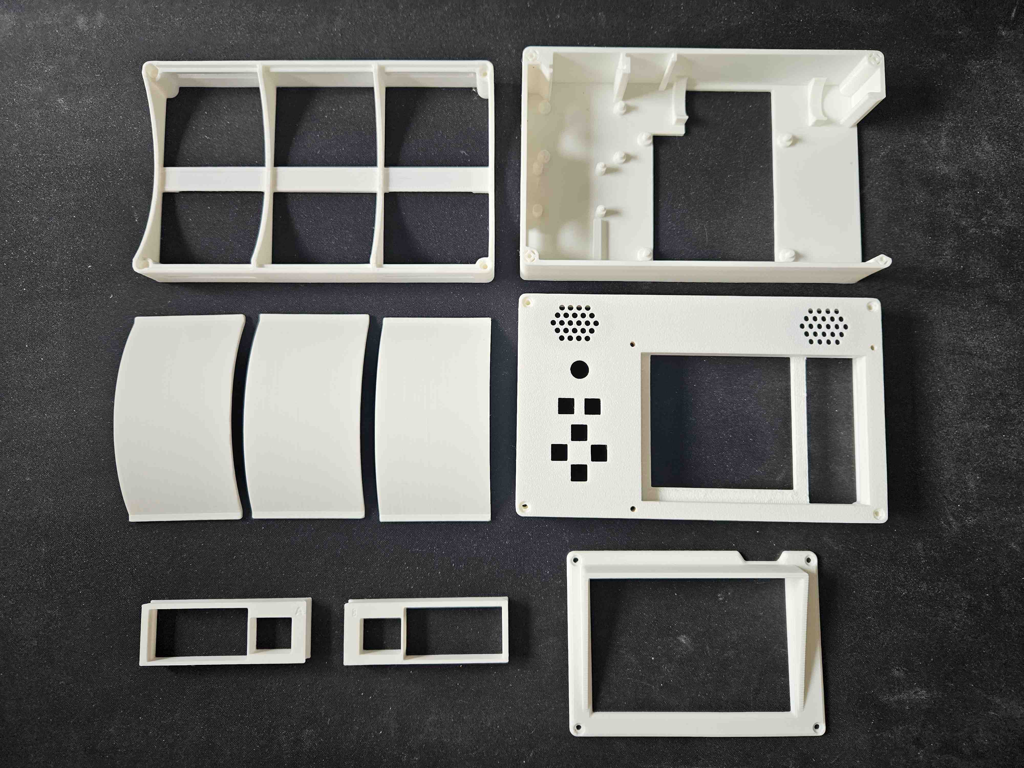
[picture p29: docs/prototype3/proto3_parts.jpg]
proto3_parts


The three arches are all the same. They will most likely require some sanding to fit perfectly flush.
You will need only one of the IO plates on the bottom left.
The glare shield can technically be skipped if you do not wish to use it.

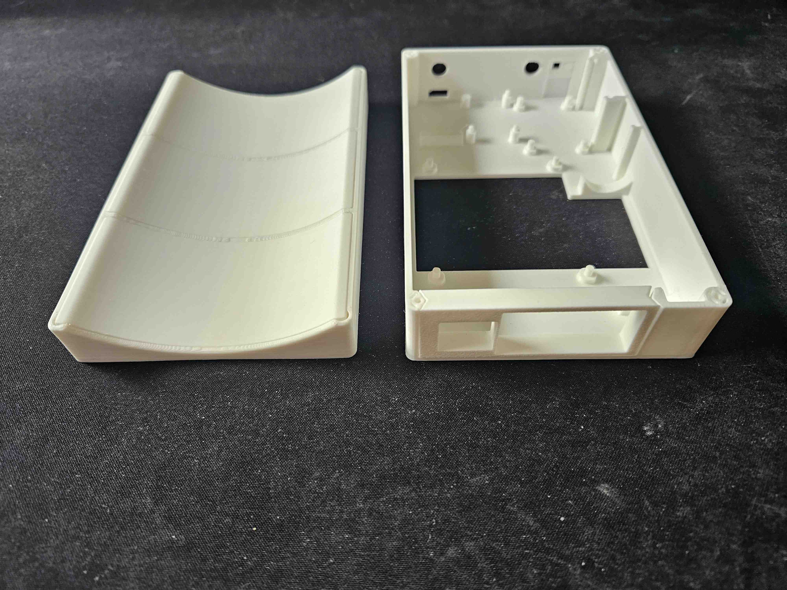
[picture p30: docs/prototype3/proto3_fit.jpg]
proto3_fit


Make sure the arches fit into the base frame and are held in place by friction. The middle one can be glued in if
needed, but the outer ones have to be removable, because they cover the bottom screws.

The IO plate for your Raspberry Pi should loosely fit into the designated space. The identifying letter on the IO plate
should face to the inside.

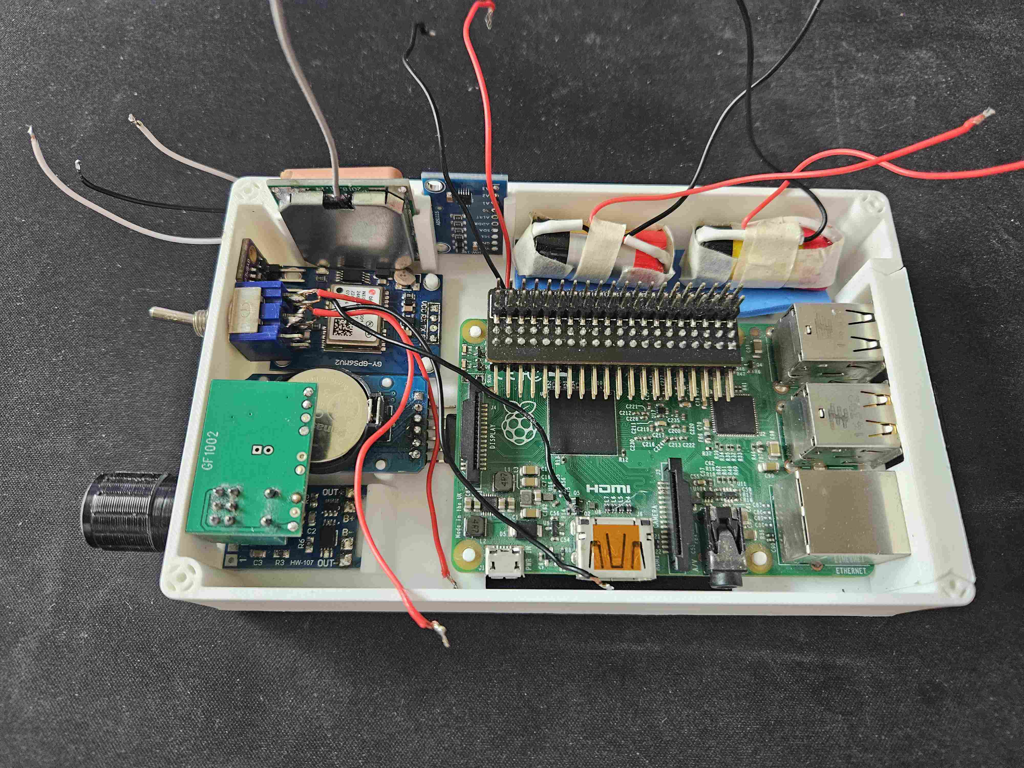
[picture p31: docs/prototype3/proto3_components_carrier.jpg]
proto3_components_carrier


This is how the components are being place in the carrier part. Make sure everything fits nicely before soldering.

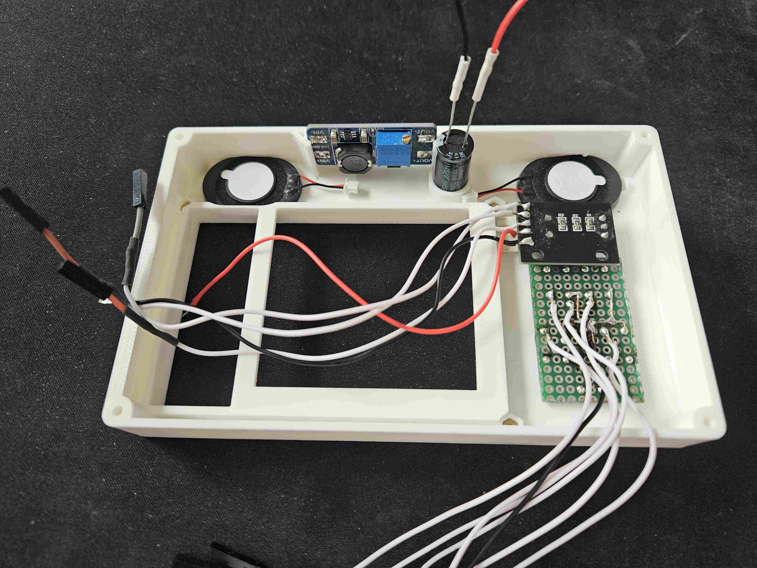
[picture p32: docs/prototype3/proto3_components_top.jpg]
proto3_components_top


And this is how the components are being placed in the top part. Also make sure everything fits nicely here. Insert
three M2 nuts into the designated spaces around the screen cutout. If it is too tricky, try inserting a screw from the
other side, adding the nut to its end, and pulling out the screw to squeeze the nut into its place. Add some glue to be
sure they are fixed in place.

The screws should grip into the holes in the carrier part, but slip through the holes in the base frame and top part.

Solder the [keypad](../keypad.md) and [power circuit](../power-circuit.md) as described, and prepare the config for the
[rotary encoder](../rotary-encoder.md).

### 2. Assembly

Now comes the funny part. Take your time, because some of the next steps can be tricky. 

The first one is still easy. Place the base frame under the carrier part and use four long screws to secure it. Then put
the arch parts in place.

#### 2.1 Power, Controls and Audio

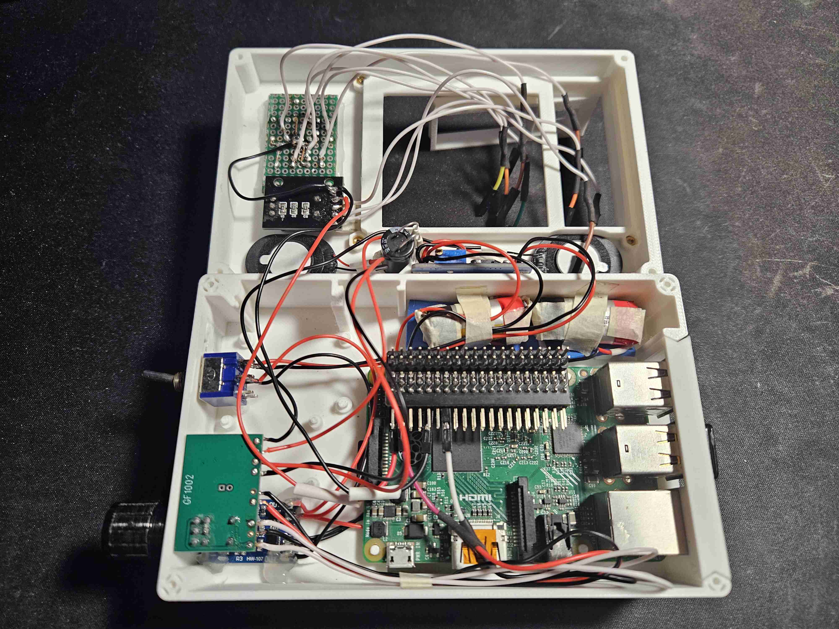
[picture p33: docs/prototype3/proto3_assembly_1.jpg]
proto3_assembly_1


Continue with the essentials, and everything that is soldered directly.

* [power circuit](../power-circuit.md)
  * solder the output of the voltage converter to the bottom of the Pi
  * solder a wire to the VIN+ of the voltage converter in preparation for [ADS1115](../ADS1115.md)
  * mount the voltage converter
  * hot-glue the capacitor next to the voltage converter
  * secure the battery with some tape
  * screw in the switch
* [PAM8403](../PAM8403.md)
  * if you choose input variant A, solder the audio lines to the bottom of the Pi
  * if you choose input variant B, connect via GPIO pins
  * mount the speakers
  * screw in the amplifier module
  * connect the wires to the Pi
* [rotary encoder](../rotary-encoder.md)
  * screw in the rotary encoder module
  * connect the wires to the Pi
* [keypad](../keypad.md)
  * hot-glue the keypad in place
  * connect the wires to the Pi (you can pigtail ground to the rotary encoders ground)

#### 2.2 GPS

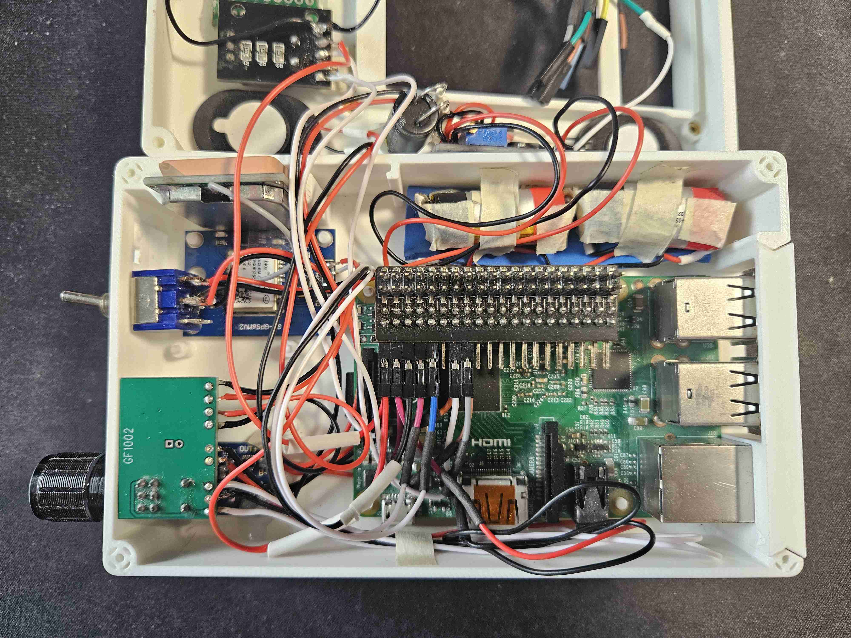
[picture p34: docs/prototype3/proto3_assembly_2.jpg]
proto3_assembly_2


Now add the GPS. The antenna should face outwards.

* [NEO-6M](../NEO-6M.md)

#### 2.3 Environment sensor, RTC and ADC

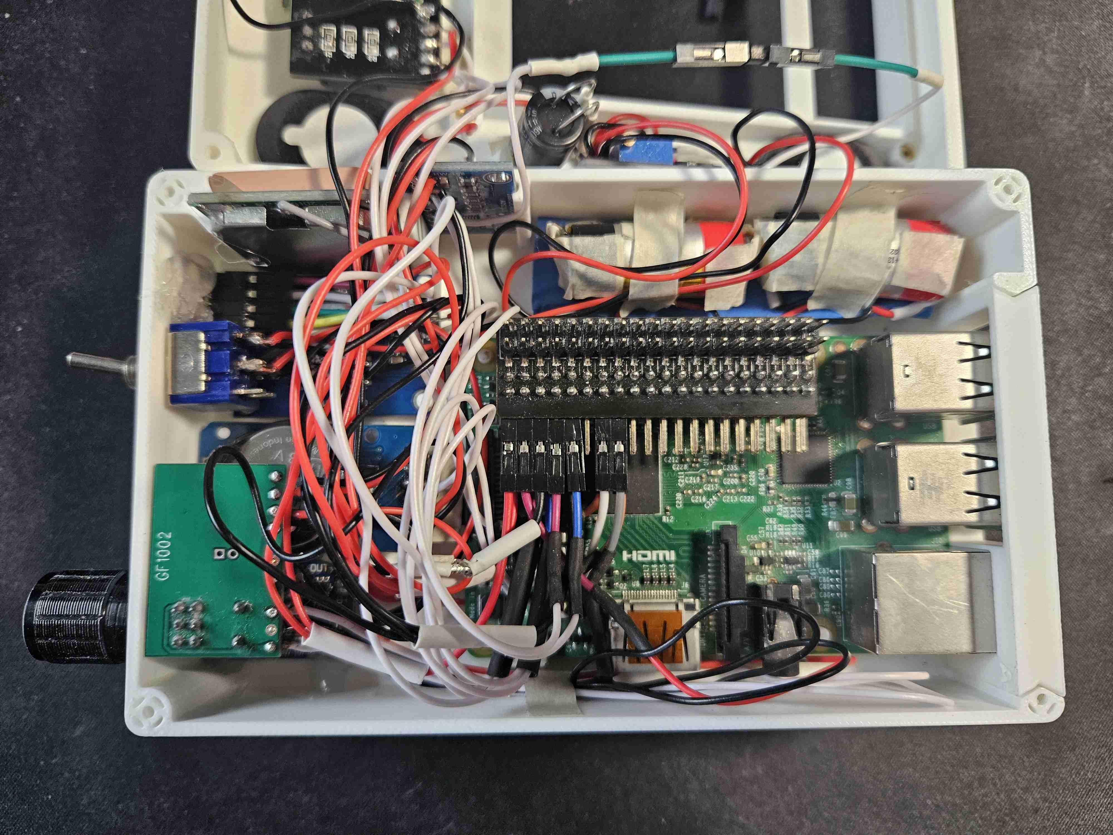
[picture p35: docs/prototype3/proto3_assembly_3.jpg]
proto3_assembly_3


Finally add the modules, that are connected via I2C.

* take a look at the module specific instructions and make sure every module works on its own
  * [BME280](../BME280.md)
  * [DS3231](../DS3231.md)
  * [ADS1115](../ADS1115.md)
* due to limited pins providing 3.3 V, prepare a common VCC connector, that connects [BME280](../BME280.md),
  [DS3231](../DS3231.md) and also the [rotary encoder](../rotary-encoder.md) (double check if you module states it needs
  5 V instead)
* similarly, prepare common SDA and SCL connectors, that connect the SDA and SCL pins of [BME280](../BME280.md),
  [DS3231](../DS3231.md) and [ADS1115](../ADS1115.md), because I2C is a bus system that shares the same wire across all
  devices
* you can do the same for ground, but it is not necessarily needed, because there are enough ground pins available on
  the Pi
* mount the RTC module (might need to add some hot-glue)
* mount the ADC module
* hot-glue the environment sensor in place

#### 2.4 Finish

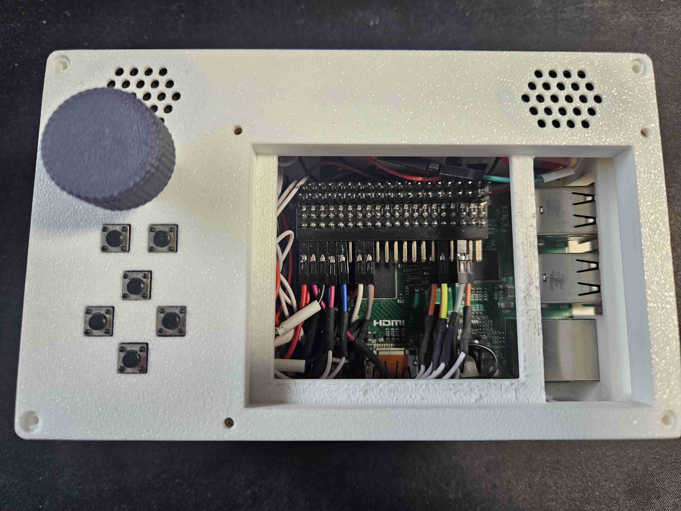
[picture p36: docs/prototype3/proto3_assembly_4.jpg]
proto3_assembly_4


Congratulations. If everything works at this point, you have now reached the final step, which is an easy one. Place the
top part on top and secure it with the longer screws in all corners except the bottom right one. Then add the glare
shield, use the last long screw in the bottom right corner, and the shorter ones in the other corners of the glare
shield.

proto3_final

### 3. Bonus

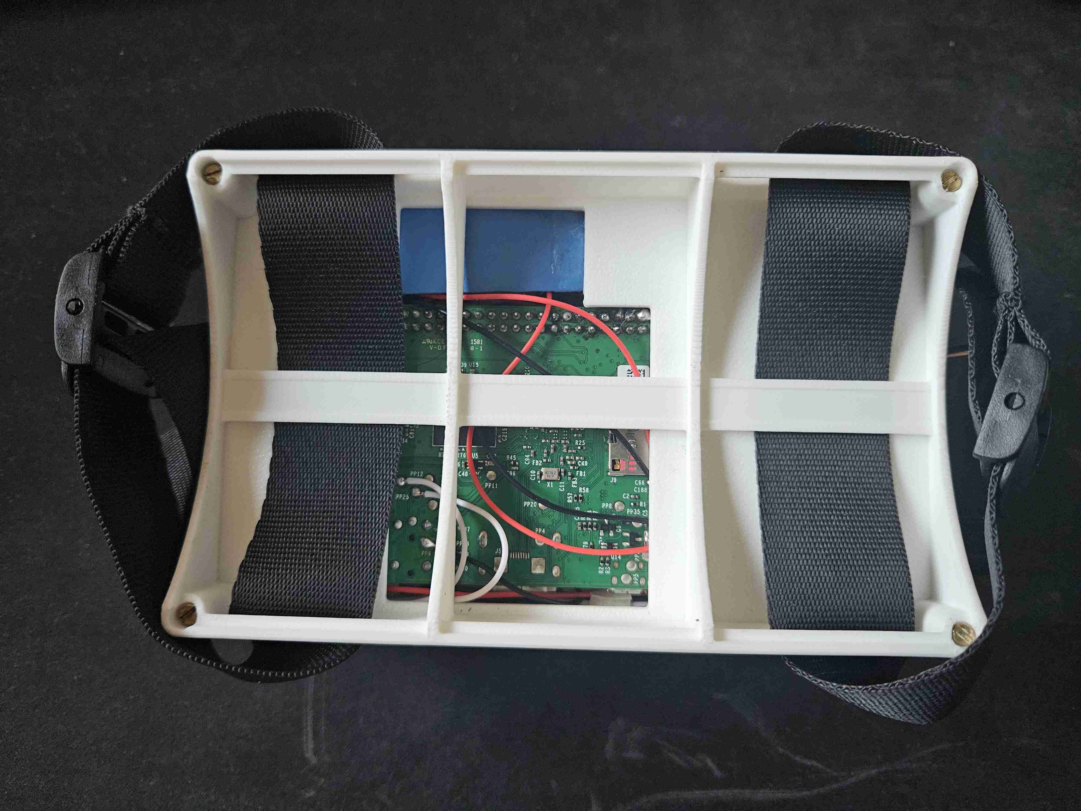
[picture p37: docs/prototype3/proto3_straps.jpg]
proto3_straps


You can now also add straps if you want, to mount the device on your forearm. The straps should not be thicker than 1 mm
and not wider than 30 mm. 

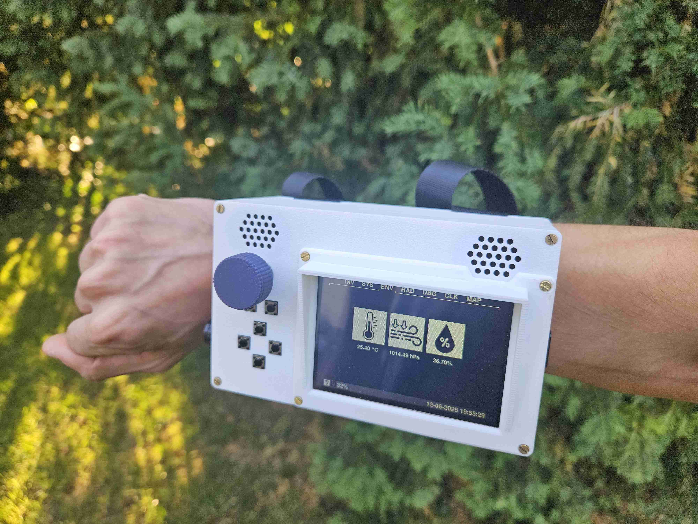
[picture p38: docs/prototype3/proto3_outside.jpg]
proto3_outside


It is not perfect yet, but it gets the job done for a demonstration.

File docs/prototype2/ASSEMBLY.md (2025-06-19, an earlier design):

Case Prototype 2
================

## Parts
* [base part](parts/Proto2.1-base.stl)
* [carrier part](parts/Proto2.1-carrier.stl)

either for type A:
* [spacer part](parts/Proto2.1-spacer.stl)
* [top part](parts/Proto2.1-top.stl)

or for type B:
* [top part no spacer](parts/Proto2.1-top-no-spacer.stl)

and also for both types:
* 8x M2 (you can shorten screws if needed)
  * 4x at least 16 mm for the bottom
  * 4x at least 24 mm for the top for type A or 12 mm for type B

**GPIO edge extension is required for type A.**

**Made for Raspberry Pi 2 Model B. Other full size boards should fit as well with some adjustments to the I/O part.**

## Goal

* make everything fit inside
* test component layout

## Evaluation

* forearm bulging radius is probably too wide for most arms to be comfortable
* more space to run wires through would be helpful
* hole for power switch is pretty tight, might be hard to mount the switch
* hole for rotary encoder is pretty tight
* mounting rails for MT3608 is pretty tight
* display might need additional support from the bottom
* misplaced stand-offs for NEO-6M
* USB ports need a bit more space
* spacer for type A is not tall enough for the extension unit
* antenna position is suboptimal

### Fixes in Prototype 2.1

* widened hole for power switch for easier mounting
* widened hole for rotary encoder
* widened mounting rails for MT3608
* additional support for display
* fixed misplaced stand-offs for NEO-6M
* more space for USB ports
* higher spacer part

## Instructions

### 1. Prepare parts

proto2_parts

The first version of these parts had a few issues. Use the parts with ``Proto2.1`` in their name instead.
The image shows the parts for type A. The top left part is slightly different for type B and does not use the top right
part.

proto2_overview

This is how the components are being placed. Make sure everything fits nicely before soldering. Some parts might still
need some sanding and smoothing, especially on the mounting rails.

The screws should grip into the four holes in the carrier part that holds the Pi and most of the other components, but
slip through the holes in the other parts. Screws will be placed from the bottom as well as from the top, and might need
to be shortened a bit. Going from both sides reduces the load on each screw and allows to use shorter screws, because
25 mm is usually already the longest variant you can get for M2 screws, which would not be enough here if going from the
top all the way to the bottom part.

Solder the [keypad](../keypad.md) and [power circuit](../power-circuit.md) as described, and prepare the config for the
[rotary encoder](../rotary-encoder.md).

### 2. Assembly

The parts are held in place in different ways. If needed, add some (more) hot glue.

| part | mounting |
|---|---|
| Raspberry Pi | stand-offs |
| display | GPIO pins |
| rotary encoder | mounting hole (nut) |
| daughter board | hot glue |
| TP4056 | hot glue |
| MT3508 | mounting rail |
| battery | hot glue / tape |
| toggle switch  | mounting hole (nut) | 
| NEO-6M module  | stand-offs |
| NEO-6M antenna | mounting rail |
| DS3231 | stand-offs |
| BME280 | hot glue |

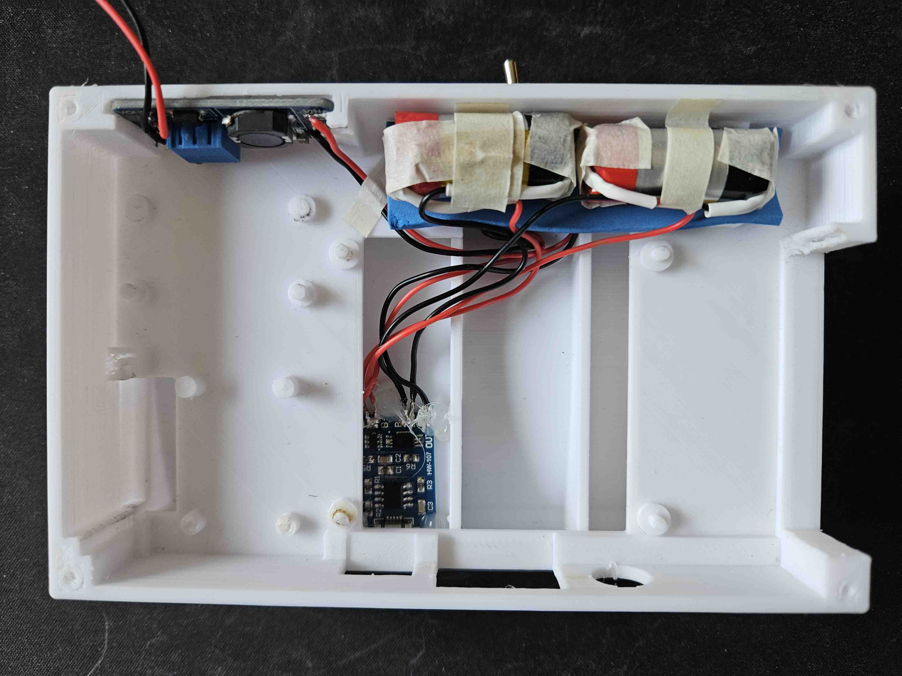
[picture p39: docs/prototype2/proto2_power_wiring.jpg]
proto2_power_wiring

* mount the toggle switch in the bottom part
* glue in the charging controller
* place the battery
* mount the MT3508 power converter
  * grind away the rest of the pins on the bottom of the board, if needed
* screw both parts together from the bottom

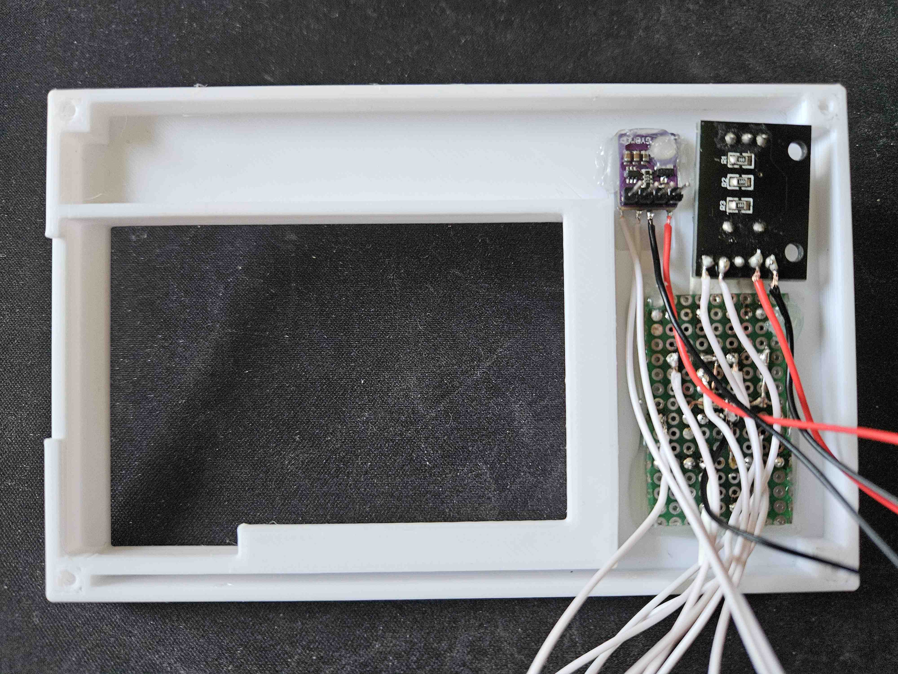
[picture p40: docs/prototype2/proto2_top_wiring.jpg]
proto2_top_wiring

* mount the rotary encoder
* glue in the keypad
* glue in the BME280 environment sensor

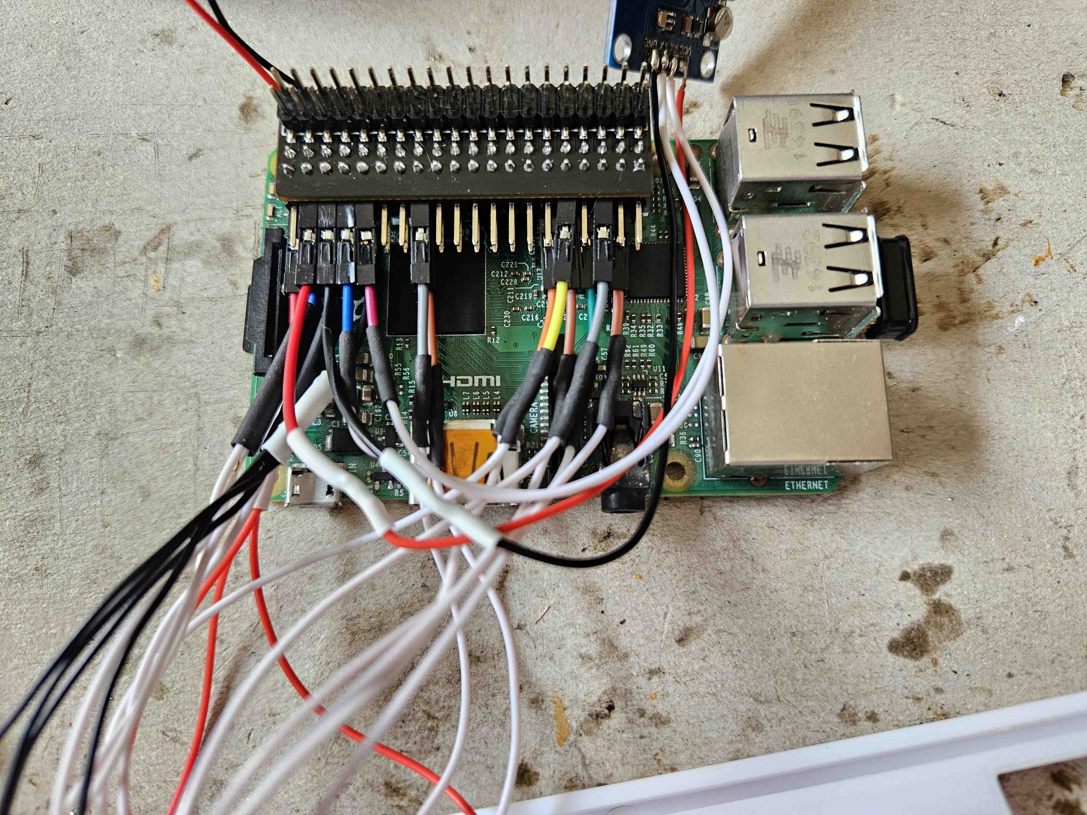
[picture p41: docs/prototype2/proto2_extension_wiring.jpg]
proto2_extension_wiring

Depending on the variant, solder all wires to the Pi as referenced, or connect them to the edge extension. Using the
extension makes it much easier, especially because there is not much space under the Pi for cable management.

Configure [BME280](../BME280.md), [DS3231](../DS3231.md) and [NEO-6M](../NEO-6M.md), as described in their instructions.

You can bundle multiple GND and VCC wires together. The I2C devices (DS3231 and BME280) also share the same pins.

Use this table for reference:

| #pin | pin name | connects |
|---|---|---|
| 1 | 3v3 power | KY-040 +, BME280 VIn, DS3231 VCC |
| 2 | 5v power | MT3608 VOut+ |
| 3 | GPIO 2 / I2C SDA  | BME280 SDA, DS3231 SDA |
| 4 | 5v power | NEO-6M VCC |
| 5 | GPIO 3 / I2C SCL  | BME280 SCL, DS3231 SCL |
| 6 | GND | MT3608 VOut-, NEO-6M GND |
| 8 | GPIO 14 / UART TX | NEO-6M RX |
| 9 | GND | KY-040 GND, keypad GND, BME280 GND, DS3231 GND |
| 10 | GPIO 15 / UART RX | NEO-6M TX |
| 13 | GPIO 27 | KY-040 SW / NC |
| 15 | GPIO 23 | KY-040 CLK |
| 16 | GPIO 22 | KY-040 DT |
| 29 | GPIO 5 | keypad UP |
| 31 | GPIO 6 | keypad DOWN |
| 32 | GPIO 12 | keypad LEFT |
| 33 | GPIO 13 | keypad RIGHT |
| 36 | GPIO 16 | keypad A |
| 37 | GPIO 26 | keypad B |

Refer to this pinout diagram from [pinout.xyz](https://pinout.xyz/):
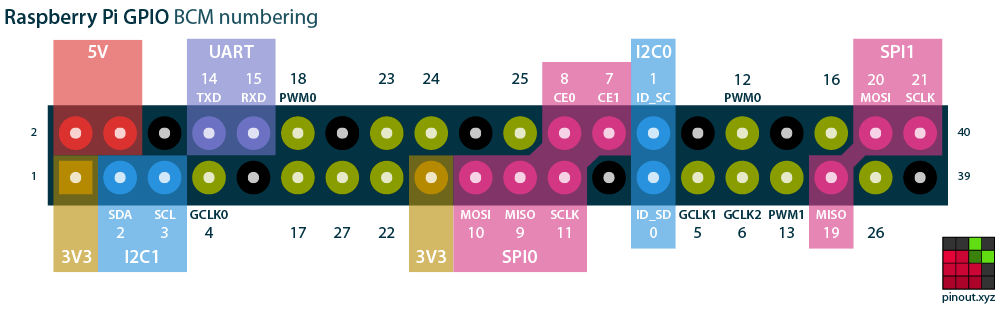
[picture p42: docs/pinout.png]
pinout


Keep in mind, that wiring diagrams and pinouts for the Pi are usually from a top view, which means you have mirror the
pinout when soldering to the bottom. Some wires might need to go through the middle of the carrier part.

proto2_placing
Put all components inside and add some hot glue if needed. Remember to also add the spacer part when using the edge
extension.

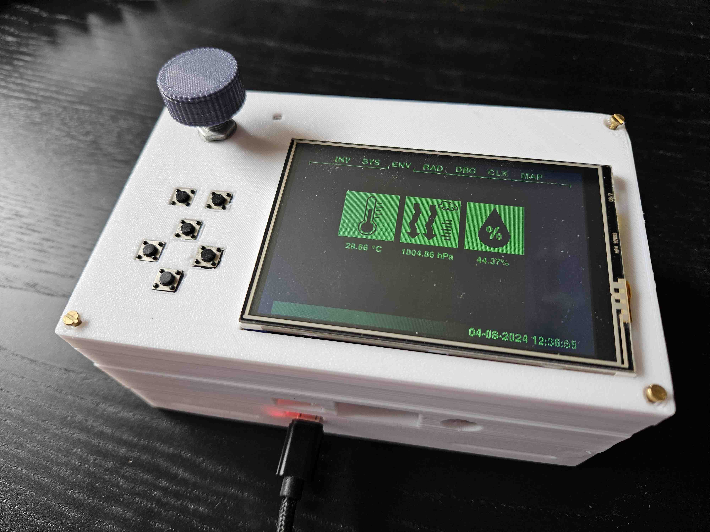
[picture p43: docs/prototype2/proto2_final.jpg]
proto2_final

Place the top part on top and secure it with screws.

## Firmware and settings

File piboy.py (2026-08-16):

import logging
import time
from contextlib import ExitStack
from datetime import datetime
from logging.config import fileConfig
from typing import Any, Callable, Generator, Self

from injector import Injector, Module, provider, singleton
from PIL import Image, ImageDraw

import environment
from app.App import App
from app.ClockApp import ClockApp
from app.DebugApp import DebugApp
from app.EnvironmentApp import EnvironmentApp
from app.FileManagerApp import FileManagerApp
from app.MapApp import MapApp
from app.RadioApp import RadioApp
from app.UpdateApp import UpdateApp
from core import resources
from core.data import ConnectionStatus, DeviceStatus
from data.BatteryStatusProvider import BatteryStatusProvider
from data.EnvironmentDataProvider import EnvironmentDataProvider
from data.LocationProvider import LocationProvider
from data.NetworkStatusProvider import NetworkStatusProvider
from data.OSMTileProvider import OSMTileProvider
from data.TileProvider import TileProvider
from environment import AppConfig, Environment
from interaction.Display import Display
from interaction.Input import Input
from interaction.UnifiedInteraction import UnifiedInteraction

fileConfig(fname='config.ini')
logger = logging.getLogger(__name__)

class AppState:

    __bit = 0

    def __init__(self, e: Environment, network_status_provider: NetworkStatusProvider,
                 location_provider: LocationProvider, battery_status_provider: BatteryStatusProvider,
                 environment_data_provider: EnvironmentDataProvider):
        self.__environment = e
        self.__network_status_provider = network_status_provider
        self.__location_provider = location_provider
        self.__battery_status_provider = battery_status_provider
        self.__environment_data_provider = environment_data_provider
        self.__image_buffer = self.__init_buffer()
        self.__apps: list[App] = []
        self.__active_app = 0

    def __init_buffer(self) -> Image.Image:
        return Image.new('RGB', self.__environment.app_config.resolution, self.__environment.app_config.background)

    def __tick(self):
        self.__bit ^= 1

    def clear_buffer(self) -> Image.Image:
        self.__image_buffer = self.__init_buffer()
        return self.__image_buffer

    def add_app(self, app: App) -> Self:
        self.__apps.append(app)
        return self

    @property
    def tick(self) -> int:
        return self.__bit

    @property
    def environment(self) -> Environment:
        return self.__environment

    @property
    def network_status_provider(self) -> NetworkStatusProvider:
        return self.__network_status_provider

    @property
    def location_provider(self) -> LocationProvider:
        return self.__location_provider

    @property
    def battery_status_provider(self) -> BatteryStatusProvider:
        return self.__battery_status_provider

    @property
    def environment_data_provider(self) -> EnvironmentDataProvider:
        return self.__environment_data_provider

    @property
    def image_buffer(self) -> Image.Image:
        return self.__image_buffer

    @property
    def apps(self) -> list[App]:
        return self.__apps

    @property
    def active_app(self) -> App:
        return self.__apps[self.__active_app]

    @property
    def active_app_index(self) -> int:
        return self.__active_app

    def next_app(self):
        self.__active_app += 1
        if not self.__active_app < len(self.__apps):
            self.__active_app = 0

    def previous_app(self):
        self.__active_app -= 1
        if self.__active_app < 0:
            self.__active_app = len(self.__apps) - 1

    def watch_function(self, display: Display):
        while True:
            now = datetime.now()
            # wait for next second
            time.sleep(1.0 - now.microsecond / 1000000.0)

            # draw the complete footer to remove existing clock display
            image, x0, y0 = draw_footer(self.image_buffer, self)
            display.show(image, x0, y0)
            self.__tick()

    def update_display(self, display: Display, partial=False):
        """Draw call that handles the complete cycle of drawing a new image to the display."""
        image = self.clear_buffer()
        app_bbox = (self.__environment.app_config.app_side_offset,
                    self.__environment.app_config.app_top_offset,
                    self.__environment.app_config.width - self.__environment.app_config.app_side_offset,
                    self.__environment.app_config.height - self.__environment.app_config.app_bottom_offset)
        x_offset, y_offset = app_bbox[0:2]
        if partial:
            for patch, x0, y0 in self.active_app.draw(image.crop(app_bbox), partial):
                display.show(patch, x0 + x_offset, y0 + y_offset)
        else:
            for patch, x0, y0 in draw_base(image, self):
                display.show(patch, x0, y0)
            for patch, x0, y0 in self.active_app.draw(image.crop(app_bbox), partial):
                image.paste(patch, (x0 + x_offset, y0 + y_offset))
            display.show(image.crop(app_bbox), x_offset, y_offset)

    def on_key_left(self, display: Display):
        self.active_app.on_key_left()
        self.update_display(display, partial=True)

    def on_key_right(self, display: Display):
        self.active_app.on_key_right()
        self.update_display(display, partial=True)

    def on_key_up(self, display: Display):
        self.active_app.on_key_up()
        self.update_display(display, partial=True)

    def on_key_down(self, display: Display):
        self.active_app.on_key_down()
        self.update_display(display, partial=True)

    def on_key_a(self, display: Display):
        self.active_app.on_key_a()
        self.update_display(display, partial=True)

    def on_key_b(self, display: Display):
        self.active_app.on_key_b()
        self.update_display(display, partial=True)

    def on_rotary_change(self, display: Display, steps: int):
        self.active_app.on_app_leave()
        self.__active_app = (self.__active_app + steps) % len(self.__apps)
        self.active_app.on_app_enter()
        self.update_display(display, partial=False)


class AppModule(Module):

    def __init__(self):
        super().__init__()
        self.__unified_instance: UnifiedInteraction | None = None

    def register_external_tk_interaction(self, tk_instance: UnifiedInteraction):
        self.__unified_instance = tk_instance

    @staticmethod
    def __create_tk_interaction(state: AppState, app_config: AppConfig) -> UnifiedInteraction:
        from interaction.TkInteraction import TkInteraction
        return TkInteraction(state.on_key_left, state.on_key_right, state.on_key_up, state.on_key_down,
                             state.on_key_a, state.on_key_b, state.on_rotary_change,
                             lambda _: None, app_config.resolution, app_config.background, app_config.accent_dark)

    @singleton
    @provider
    def provide_environment(self) -> Environment:
        environment.configure()
        try:
            return environment.load()
        except FileNotFoundError:
            e = Environment()
            environment.save(e)
            return e

    @singleton
    @provider
    def provide_app_config(self, e: Environment) -> AppConfig:
        return e.app_config

    @singleton
    @provider
    def provide_app_state(self, e: Environment, network_status_provider: NetworkStatusProvider,
                          location_provider: LocationProvider,
                          battery_status_provider: BatteryStatusProvider,
                          environment_data_provider: EnvironmentDataProvider) -> AppState:
        return AppState(e, network_status_provider, location_provider, battery_status_provider,
                        environment_data_provider)

    @singleton
    @provider
    def provide_environment_data_service(self, e: Environment) -> EnvironmentDataProvider:
        if e.is_raspberry_pi:
            from data.BME280EnvironmentDataProvider import BME280EnvironmentDataProvider
            return BME280EnvironmentDataProvider(e.env_sensor_config.port, e.env_sensor_config.address)
        else:
            from data.FakeEnvironmentDataProvider import FakeEnvironmentDataProvider
            return FakeEnvironmentDataProvider()

    @singleton
    @provider
    def provide_location_service(self, e: Environment) -> LocationProvider:
        if e.is_raspberry_pi:
            from data.SerialGPSLocationProvider import SerialGPSLocationProvider
            return SerialGPSLocationProvider(e.gps_module_config.port, baud_rate=e.gps_module_config.baud_rate)
        else:
            from data.IPLocationProvider import IPLocationProvider
            return IPLocationProvider(apply_inaccuracy=True)

    @singleton
    @provider
    def provide_tile_service(self, e: Environment) -> TileProvider:
        return OSMTileProvider(e.app_config.background, e.app_config.accent, e.app_config.font_standard)

    @singleton
    @provider
    def provide_network_status_service(self, e: Environment) -> NetworkStatusProvider:
        if e.is_raspberry_pi:
            from data.NetworkManagerStatusProvider import NetworkManagerStatusProvider
            return NetworkManagerStatusProvider()
        else:
            from data.FakeNetworkStatusProvider import FakeNetworkStatusProvider
            return FakeNetworkStatusProvider()

    @singleton
    @provider
    def provide_battery_status_service(self, e: Environment) -> BatteryStatusProvider:
        if e.is_raspberry_pi:
            from data.ADS1115BatteryStatusProvider import ADS1115BatteryStatusProvider
            return ADS1115BatteryStatusProvider(e.adc_config.port, e.adc_config.address)
        else:
            from data.FakeBatteryStatusProvider import FakeBatteryStatusProvider
            return FakeBatteryStatusProvider()

    @singleton
    @provider
    def provide_draw_callback(self, state: AppState, display: Display) -> Callable[[bool], None]:
        return lambda partial: state.update_display(display, partial)

    @singleton
    @provider
    def provide_display(self, e: Environment, state: AppState) -> Display:
        if e.is_raspberry_pi:
            from interaction.ILI9486Display import ILI9486Display

            spi_device_config = e.display_config.display_device
            return ILI9486Display((spi_device_config.bus, spi_device_config.device),
                                  e.display_config.dc_pin, e.display_config.rst_pin, e.display_config.flip_display)
        else:
            instance = self.__unified_instance
            if instance is None:
                instance = self.__create_tk_interaction(state, e.app_config)
                self.__unified_instance = instance
            return instance

    @singleton
    @provider
    def provide_input(self, e: Environment, state: AppState, display: Display) -> Input:
        if e.is_raspberry_pi:
            from interaction.GPIOInput import GPIOInput
            from interaction.ILI9486Display import ILI9486Display

            def reset_and_init():
                # make sure that display is ILI9486Interface to call the reset function, should be always true
                if isinstance(display, ILI9486Display):
                    display.reset()
                display.show(state.clear_buffer(), 0, 0)

            return GPIOInput(e.keypad_config.left_pin, e.keypad_config.right_pin,
                             e.keypad_config.up_pin, e.keypad_config.down_pin,
                             e.keypad_config.a_pin, e.keypad_config.b_pin,
                             e.rotary_config.rotary_device, e.rotary_config.sw_pin,
                             lambda: state.on_key_left(display), lambda: state.on_key_right(display),
                             lambda: state.on_key_up(display), lambda: state.on_key_down(display),
                             lambda: state.on_key_a(display), lambda: state.on_key_b(display),
                             lambda steps: state.on_rotary_change(display, steps),
                             reset_and_init)
        else:
            instance = self.__unified_instance
            if instance is None:
                instance = self.__create_tk_interaction(state, e.app_config)
                self.__unified_instance = instance
            return instance


def draw_footer(image: Image.Image, state: AppState) -> tuple[Image.Image, int, int]:
    width, height = state.environment.app_config.resolution
    footer_height = 20  # height of the footer
    footer_bottom_offset = 3  # spacing to the bottom
    icon_padding = 3 # padding between status icons
    footer_side_offset = state.environment.app_config.app_side_offset  # spacing to the sides
    font = state.environment.app_config.font_header
    draw = ImageDraw.Draw(image)

    start = (footer_side_offset, height - footer_height - footer_bottom_offset)
    end = (width - footer_side_offset - 1, height - footer_bottom_offset - 1)
    cursor_x, cursor_y = start
    connection_status_color = {
        ConnectionStatus.CONNECTED: state.environment.app_config.accent,
        ConnectionStatus.DISCONNECTED: state.environment.app_config.accent if state.tick else state.environment.app_config.background
    }
    device_status_color = {
        DeviceStatus.OPERATIONAL: state.environment.app_config.accent,
        DeviceStatus.NO_DATA: state.environment.app_config.accent if state.tick else state.environment.app_config.background,
        DeviceStatus.UNAVAILABLE: state.environment.app_config.background
    }

    # reset area
    draw.rectangle(start + end, fill=state.environment.app_config.accent_dark)

    # draw network status
    nw_status_padding = (footer_height - resources.network_icon.height) // 2
    nw_status_color = connection_status_color[state.network_status_provider.get_connection_status()]
    draw.bitmap((cursor_x + icon_padding, cursor_y + nw_status_padding), resources.network_icon, fill=nw_status_color)
    cursor_x += resources.network_icon.width + icon_padding

    # draw gps status
    gps_status_padding = (footer_height - resources.gps_icon.height) // 2
    gps_status_color = device_status_color[state.location_provider.get_device_status()]
    draw.bitmap((cursor_x + icon_padding, cursor_y + gps_status_padding), resources.gps_icon, fill=gps_status_color)
    cursor_x += resources.gps_icon.width + icon_padding

    # draw battery status
    state_of_charge_str = f'{state.battery_status_provider.get_state_of_charge():.0%}'
    _, _, text_width, text_height = font.getbbox(state_of_charge_str)
    text_width, text_height = round(text_width), round(text_height)
    text_padding = (footer_height - text_height) // 2
    draw.text((cursor_x + icon_padding, cursor_y + text_padding), state_of_charge_str,
              state.environment.app_config.accent, font=font)
    cursor_x += text_width

    # draw time
    date_str = datetime.now().strftime('%d-%m-%Y %H:%M:%S')
    _, _, text_width, text_height = font.getbbox(date_str)
    text_width, text_height = round(text_width), round(text_height)
    text_padding = (footer_height - text_height) // 2
    draw.text((width - footer_side_offset - text_padding - text_width, cursor_y + text_padding), date_str,
              state.environment.app_config.accent, font=font)

    x0, y0 = start
    end = end[0] + 1, end[1] + 1
    return image.crop(start + end), x0, y0


def draw_header(image: Image.Image, state: AppState) -> tuple[Image.Image, int, int]:
    width, height = state.environment.app_config.resolution
    vertical_line = 5  # vertical limiter line
    header_top_offset = state.environment.app_config.app_top_offset - vertical_line  # base for header
    header_side_offset = state.environment.app_config.app_side_offset  # spacing to the sides
    app_spacing = 20  # space between app headers
    app_padding = 5  # space around app header
    draw = ImageDraw.Draw(image)
    color_background = state.environment.app_config.background
    color_accent = state.environment.app_config.accent

    # draw base header lines
    start = (header_side_offset, header_top_offset + vertical_line)
    end = (header_side_offset, header_top_offset)
    draw.line(start + end, fill=color_accent)
    start = end
    end = (width - header_side_offset - 1, header_top_offset)
    draw.line(start + end, fill=color_accent)
    start = end
    end = (width - header_side_offset - 1, header_top_offset + vertical_line)
    draw.line(start + end, fill=color_accent)

    # draw app short name header
    font = state.environment.app_config.font_header
    max_text_width = width - (2 * header_side_offset)
    app_text_width = sum(int(font.getbbox(app.title)[2]) for app in state.apps) + (len(state.apps) - 1) * app_spacing
    cursor = header_side_offset + (max_text_width - app_text_width) // 2
    for app in state.apps:
        _, _, text_width, text_height = map(int, font.getbbox(app.title))
        draw.text((cursor, header_top_offset - text_height - app_padding), app.title, color_accent, font=font)
        if app is state.active_app:
            start = (cursor - app_padding, header_top_offset - vertical_line)
            end = (cursor - app_padding, header_top_offset)
            draw.line(start + end, fill=color_accent)
            start = end
            end = (cursor + text_width + app_padding, header_top_offset)
            draw.line(start + end, fill=color_background)
            start = end
            end = (cursor + text_width + app_padding, header_top_offset - vertical_line)
            draw.line(start + end, fill=color_accent)
        cursor = cursor + text_width + app_spacing

    partial_start = (header_side_offset, 0)
    partial_end = (width - header_side_offset, header_top_offset + vertical_line)
    x0, y0 = partial_start
    return image.crop(partial_start + partial_end), x0, y0


def draw_base(image: Image.Image, state: AppState) -> Generator[tuple[Image.Image, int, int], Any, None]:
    yield draw_header(image, state)
    yield draw_footer(image, state)


if __name__ == '__main__':
    injector = Injector([AppModule()])
    app_state = injector.get(AppState)

    DISPLAY = injector.get(Display)
    INPUT = injector.get(Input)

    app_state.add_app(injector.get(FileManagerApp)) \
        .add_app(injector.get(UpdateApp)) \
        .add_app(injector.get(EnvironmentApp)) \
        .add_app(injector.get(RadioApp)) \
        .add_app(injector.get(DebugApp)) \
        .add_app(injector.get(ClockApp)) \
        .add_app(injector.get(MapApp))

    # start the auto mount service on raspberry
    if injector.get(Environment).is_raspberry_pi:
        from core.udev_service import UDevService
        udev_service = UDevService()
        udev_service.start()

    # initially draw the empty buffer to initialize all pixels on the hardware module
    DISPLAY.show(app_state.image_buffer, 0, 0)
    # then continue with the initial draw call
    app_state.update_display(DISPLAY)
    app_state.active_app.on_app_enter()

    with ExitStack() as stack:
        stack.enter_context(DISPLAY)
        stack.enter_context(INPUT)
        stack.enter_context(injector.get(LocationProvider))
        stack.enter_context(injector.get(BatteryStatusProvider))
        stack.enter_context(injector.get(EnvironmentDataProvider))
        try:
            # blocking function that updates the clock
            app_state.watch_function(DISPLAY)
        except KeyboardInterrupt:
            pass

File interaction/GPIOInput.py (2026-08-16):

import logging
import threading
from typing import Callable

import evdev
import RPi.GPIO as GPIO

from core.decorator import override
from interaction.Input import Input

logger = logging.getLogger('gpio')

class GPIOInput(Input):

    def __init__(self, key_left: int, key_right: int, key_up: int, key_down: int, key_a: int, key_b: int,
                 rotary_device: str, rotary_switch: int,
                 on_key_left: Callable[[], None], on_key_right: Callable[[], None],
                 on_key_up: Callable[[], None], on_key_down: Callable[[], None],
                 on_key_a: Callable[[], None], on_key_b: Callable[[], None],
                 on_rotary_change: Callable[[int], None],
                 on_rotary_switch: Callable[[], None], debounce: int = 50):
        super().__init__(on_key_left, on_key_right, on_key_up, on_key_down, on_key_a, on_key_b, on_rotary_change,
                         on_rotary_switch)
        self.__encoder = evdev.InputDevice(rotary_device)
        self.__pending_steps = 0
        self.__steps_condition = threading.Condition()

        # keys setup
        GPIO.setup(key_left, GPIO.IN, pull_up_down=GPIO.PUD_UP)
        GPIO.setup(key_right, GPIO.IN, pull_up_down=GPIO.PUD_UP)
        GPIO.setup(key_up, GPIO.IN, pull_up_down=GPIO.PUD_UP)
        GPIO.setup(key_down, GPIO.IN, pull_up_down=GPIO.PUD_UP)
        GPIO.setup(key_a, GPIO.IN, pull_up_down=GPIO.PUD_UP)
        GPIO.setup(key_b, GPIO.IN, pull_up_down=GPIO.PUD_UP)

        # rotary setup
        GPIO.setup(rotary_switch, GPIO.IN, pull_up_down=GPIO.PUD_UP)

        # keys event callbacks
        GPIO.add_event_detect(key_left, GPIO.RISING, callback=self.__gpio_left, bouncetime=debounce)
        GPIO.add_event_detect(key_right, GPIO.RISING, callback=self.__gpio_right, bouncetime=debounce)
        GPIO.add_event_detect(key_up, GPIO.RISING, callback=self.__gpio_up, bouncetime=debounce)
        GPIO.add_event_detect(key_down, GPIO.RISING, callback=self.__gpio_down, bouncetime=debounce)
        GPIO.add_event_detect(key_a, GPIO.RISING, callback=self.__gpio_a, bouncetime=debounce)
        GPIO.add_event_detect(key_b, GPIO.RISING, callback=self.__gpio_b, bouncetime=debounce)

        # rotary event callbacks
        GPIO.add_event_detect(rotary_switch, GPIO.RISING, callback=self.__gpio_rotary_switch, bouncetime=debounce)

        threading.Thread(target=self.__encoder_listener, daemon=True).start()
        threading.Thread(target=self.__encoder_dispatcher, daemon=True).start()

    def __encoder_listener(self):
        # ref: https://github.com/raphaelyancey/pyKY040 (cannot use this lib directly, because it uses the old GPIO lib)
        for event in self.__encoder.read_loop():
            steps = self.__event_to_steps(event)
            if steps != 0:
                with self.__steps_condition:
                    self.__pending_steps += steps
                    self.__steps_condition.notify()

    def __encoder_dispatcher(self):
        while True:
            with self.__steps_condition:
                while self.__pending_steps == 0:
                    self.__steps_condition.wait()
                steps = self.__pending_steps
                self.__pending_steps = 0
            if abs(steps) > 1:
                logger.debug(f'coalesced {abs(steps)} rotary steps into one dispatch')
            self.on_rotary_change(steps)

    @staticmethod
    def __event_to_steps(event) -> int:
        if event.type == 2:
            if event.value == -1:
                return 1
            elif event.value == 1:
                return -1
        return 0

    @override
    def close(self):
        GPIO.cleanup()

    def __gpio_left(self, _):
        self.on_key_left()

    def __gpio_right(self, _):
        self.on_key_right()

    def __gpio_up(self, _):
        self.on_key_up()

    def __gpio_down(self, _):
        self.on_key_down()

    def __gpio_a(self, _):
        self.on_key_a()

    def __gpio_b(self, _):
        self.on_key_b()

    def __gpio_rotary_switch(self, _):
        self.on_rotary_switch()

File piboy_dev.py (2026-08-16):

import threading

from injector import Injector

from app.ClockApp import ClockApp
from app.DebugApp import DebugApp
from app.EnvironmentApp import EnvironmentApp
from app.FileManagerApp import FileManagerApp
from app.MapApp import MapApp
from app.RadioApp import RadioApp
from app.UpdateApp import UpdateApp
from environment import Environment
from interaction.SelfManagedTkInteraction import SelfManagedTkInteraction
from piboy import AppModule, AppState

"""
This pi-boy script uses the SelfManagedTkInteraction, which follows the usual mainloop approach. This makes it
compatible with MacOS and maybe other desktop environments that require UI draw calls from a main thread only. Other
systems may continue to use the other script, that is also made for the raspberry pi.
"""
if __name__ == '__main__':
    module = AppModule()
    injector = Injector([module])

    env = injector.get(Environment)
    app_state = injector.get(AppState)

    __tk = SelfManagedTkInteraction(app_state.on_key_left, app_state.on_key_right,
                                    app_state.on_key_up, app_state.on_key_down,
                                    app_state.on_key_a, app_state.on_key_b,
                                    app_state.on_rotary_change, lambda _: None,
                                    env.app_config.resolution, env.app_config.background, env.app_config.accent_dark)

    module.register_external_tk_interaction(__tk)
    app_state.add_app(injector.get(FileManagerApp)) \
        .add_app(injector.get(UpdateApp)) \
        .add_app(injector.get(EnvironmentApp)) \
        .add_app(injector.get(RadioApp)) \
        .add_app(injector.get(DebugApp)) \
        .add_app(injector.get(ClockApp)) \
        .add_app(injector.get(MapApp))

    # initial draw
    app_state.update_display(__tk)
    app_state.active_app.on_app_enter()

    # watch function has to run in the background, because Tkinter mainloop must be in the main thread
    threading.Thread(target=app_state.watch_function, args=(__tk, ), daemon=True).start()

    try:
        # blocking run function
        __tk.run()
    except KeyboardInterrupt:
        pass
    finally:
        __tk.close()

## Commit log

2022-05-16 complete refactoring to avoid circular imports
    [BaseInput.py, GPIOInput.py, ILI9486Interface.py]
2022-05-16 state object that keeps track of current application status, partial rendering of the clock
2022-05-16 defined button pins as input
2022-05-16 class for SPI device config
2022-05-17 fixed the missing begin statement to initialized the display
    [ILI9486Interface.py]
2022-05-17 fixed wrong pin number, display should be working now
    [ILI9486Interface.py]
2022-05-17 changed filtering, setting index to last directory when leaving directory
2022-05-28 map marker of current location
2022-05-28 tile provider has zoom range, implemented buttons a and b
2022-06-07 added config for flipping spi display module
    [ILI9486Interface.py]
2022-07-22 no updating of map app when using buttons
2022-07-29 added missing user agent and extended error logging
    [OSMTileProvider.py]
2022-11-17 block flag in ILI9486Interface to avoid overlapping draw calls caused by callbacks
    [ILI9486Interface.py]
2022-11-17 rotary encoder implementation
2022-11-30 refactoring
    Applied cleaner code suggestions
    -avoiding utils
    -avoiding base and abstract prefixes
    [GPIOInput.py, ILI9486Interface.py, IPLocationProvider.py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]
2023-01-22 merged display function like in reference driver project
2023-02-26 small retry decorator to fix connection error caused by not established wifi connection when starting at reboot
    [IPLocationProvider.py]
2023-04-11 stl files for first prototype case
    [Proto1-base.stl, Proto1-top.stl]
2023-04-16 docs for proto1 assembly
2023-04-19 version 1.1 prototype case parts + docs
    [Proto1.1-base.stl, Proto1.1-top.stl]
2023-04-20 debug app to test buttons
2023-04-28 Revert "huge refactoring for more code structure and reusability"
    This reverts commit 40aa46f879eac679b653c9b141f18d1c1994f7c4.
    [piboy.py]
2023-05-09 caching of OSM tiles for a fixed duration
    [OSMTileProvider.py]
2023-05-11 error handling in OSMTileProvider
    [OSMTileProvider.py]
2023-05-30 just passing a tuple for spi config
2023-06-05 fixed the footer clock that I broke several commits ago (text with the same color as the background is not visible, obviously)
    [piboy.py]
2023-07-02 needs a dependency on raspberry, technically works so far but it is pretty load, no volume control
2023-07-03 volume control, at least for raspberry pi
2023-07-03 noinspection und noqa comments for code inspection warnings
2023-07-04 added volume info, currently playing info
2023-10-08 added I2CConfig to environment, default address 0x76, some boards might use 0x77 instead
2023-10-08 data provider for environment readings, mock implementation with some random noise
    [BME280EnvironmentDataProvider.py, EnvironmentDataProvider.py, FakeEnvironmentDataProvider.py]
2024-02-07 Radio app does not try to play a track if there are no tracks
2024-02-09 checking if running on pi if config is missing an setting dev mode accordingly
    [piboy.py]
2024-02-09 nah, this broke stuff
    This reverts commit c3816b61dd7a93d59d97d79f5a2be27e4ae43bec.
    [environment.py]
2024-02-12 mypy type fixes (piboy.py)
    [piboy.py]
2024-02-12 mypy type fixes (environment.py - fonts)
    [environment.py]
2024-02-12 mypy type fixes (various)
    [TileProvider.py, TkInterface.py]
2024-02-12 mypy type fixes (TkInterface.py)
    [TkInterface.py]
2024-02-12 mypy type fixes (piboy_dev.py)
    [piboy_dev.py]
2024-02-26 switching commit activity and last commit relative to develop branch
2024-02-26 raise error on type mismatch
    [environment.py]
2024-04-15 files for proto 2
    [Proto2-base.stl, Proto2-carrier.stl, Proto2-spacer.stl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]
2024-05-03 proto2.1 revision
    [Proto2-Proto2.1-spacer.stl, Proto2.1-base.stl, Proto2.1-carrier.stl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]
2024-05-03 restructured docs, added base for prototype 2 assembly
    [Proto1-base.stl, Proto1-top.stl, Proto1.1-base.stl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]
2024-05-05 component placing
    [Proto2.1-carrier.stl, Proto2.1-top-no-spacer.stl, Proto2.1-top.stl]
2024-05-05 usb ports space
    [Proto2-spacer.stl, Proto2.1-spacer.stl, Proto2.1-top-no-spacer.stl]
2024-05-05 wasn't actually an issue
    [Proto2.1-carrier.stl]
2024-05-06 power circuit
2024-05-28 documenting screws
2024-07-03 flashed a new RPI and started to check what we really need now on debian bookworm
    * replaced RPi.GPIO with rpi-lgpio
    * added activation of SPI and I2C to the instructions
    * started to check what we really need
    * added isssues to the roadmap
2024-07-07 added pin-out diagram from pinout.xyz
2024-07-07 note to the keypad on what legs to solder
2024-07-17 new spacer part for extension
    [Proto2.1-spacer.stl]
2024-07-18 testing rotary encoder as device instead of polling
2024-07-18 rotaray encoder config mentioned in assembly
2024-07-18 referenced source of event based rotary encoder
2024-08-04 added images and description for prototype 2 assembly
2024-08-04 keypad and rotary encoder to module specific instructions, typo
2024-08-04 typing fixed in yaml constructor functions
    [environment.py]
2024-08-04 moved wiring table to the assembly part
2024-08-05 added display reset as debugging function on rotary switch
    -also fixed a typo in the self managed TK interface filename
    -cleaned up leftovers from the polling approach for the rotary encoder
    [GPIOInput.py, ILI9486Interface.py, Input.py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]
2024-08-05 noted suboptimal placement of the antenna
2024-08-05 RadioApp is now selfupdating and shows track progress
2024-08-05 fixed RadioApp constructor in piboy_dev
    [piboy_dev.py]
2024-08-05 also resetting frame counter
2024-08-22 implemented override in most cases to ensure code quality
    app provides now default implementations for button events instead of abstract ones to avoid empty function declarations
    [BME280EnvironmentDataProvider.py, FakeEnvironmentDataProvider.py, GPIOInput.py]
2024-08-25 flip_display moved to display_config as well
    [environment.py, piboy.py]
2024-08-31 fixed wrong key callback
    [piboy.py]
2024-09-01 workaround to register the self managed tkinter
    [SelfManagedTkInterface.py, piboy.py, piboy_dev.py]
2024-09-04 render thread for SPI display to avoid missing a render call
    [ILI9486Display.py, SelfManagedTkInteraction.py, TkInteraction.py]
2024-09-18 import sorting
    [.isort.cfg]
2024-09-18 fixed imports from resources
    [piboy.py]
2024-09-24 implemented a continue to next track for RadioApp
2024-10-02 base provider for battery state of charge
2024-10-02 broken import.. why does pycharm keep doing this..
    [piboy.py]
2024-10-02 smoothing state of charge from last ten readings
2024-10-09 avoid cpu load when connection to gps module does not work
    [SerialGPSLocationProvider.py]
2024-10-11 single ConnectionStatus enum, some data provider can report their device status
2024-10-27 partially reverted commit, multiprocessing seems to have issues with GPIO or SPI
    [ILI9486Display.py]
2024-10-27 reverted commit completely because multithreading is not a 1:1 replacement for threading
    issue: properties changes by multiprocessing do not propagate back to the main process
    [ILI9486Display.py, NetworkManagerStatusProvider.py, SerialGPSLocationProvider.py]
2025-01-03 new icon for atmospheric pressure
2025-01-05 that nasty little line claimed the serial device and forced the other io wrapper to always fail
    probably caused by some failed autocomplete
    also reading all available entries at once and processing them one by one
    [SerialGPSLocationProvider.py]
2025-01-07 ConnectionStatus renamed to DeviceStatus and introduced UNAVAILABLE status
2025-01-07 makes sense to separate network connection status from other device status
2025-01-18 same offset fix here to make sure both sides have the equal amount of empty space
    [piboy.py]
2025-01-18 tiny fixed to make sure the drawn area has the right size as well as the cropped area, typical off-by-one issue
    [piboy.py]
2025-01-20 also draw clear buffer on rotary switch
2025-01-21 debug app can display device status
2025-01-23 dynamically deciding is platform is raspberry pi, making dev_mode effectively unused now
2025-01-29 quick and dirty auto mounter written in python
2025-01-29 fixed thread
2025-01-29 readme update (auto mount is done more or less)
2025-03-30 made GPIO extension a generally required part looking forward to prototype 3
2025-03-30 own readme for the power circuit
2025-03-30 same path layout as everywhere else, added power circuit link
2025-03-30 rpi 5 features an own RTC that just requires a separate battery
2025-04-14 optional capacitor to power circuit
2025-04-16 added wiring pins to keypad instructions
2025-06-09 sample code for testing ADS1115
2025-06-09 assembly and parts for prototype 3
    [Proto3-part-base-arch-3x.stl, Proto3-part-base-frame.stl, Proto3-part-carrier-optimized.stl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]
2025-06-12 docs for straps
2026-05-20 transformed to pyproject.toml, using pyILI9486 package, removed local driver code
2026-08-14 silly easy fix for audio cracks on Pi, due to draw calls and SPI transfer consuming CPU
2026-08-15 OSMTileProvider improvement, LRU cached image objects and correct PIL file handling
    [OSMTileProvider.py]
2026-08-16 on_rotary_change instead of _increase and _decrease to be able to skip steps on Pi when scrolling fast to skip draw calls and improve latency
    [GPIOInput.py, Input.py, SelfManagedTkInteraction.py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]
2026-08-16 fix NullApp not following the current generator style drawing all other apps are using
2026-08-16 moved class attributes to instance attributes where they are used as instance attributes and would fail on a second instance
    [ADS1115BatteryStatusProvider.py, piboy.py]
